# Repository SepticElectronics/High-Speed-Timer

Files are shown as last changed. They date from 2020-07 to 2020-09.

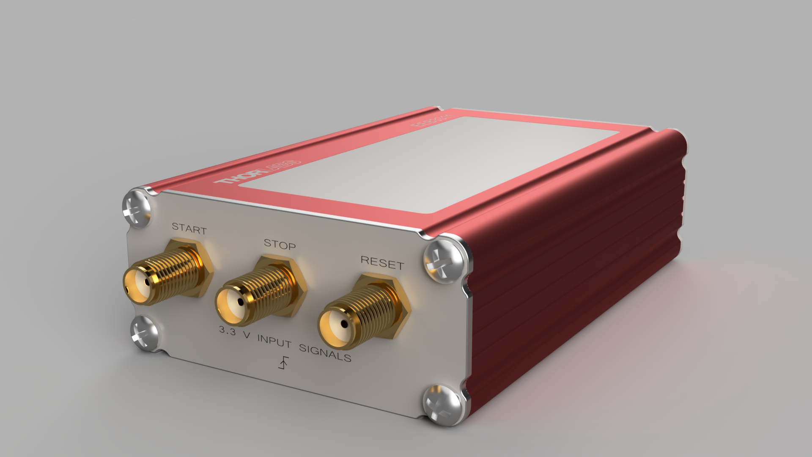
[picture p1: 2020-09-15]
PrecisionTimer_RevG.1/render/Assembly_2020-Sep-15_06-22-50PM-000_CustomizedView11693946408.png

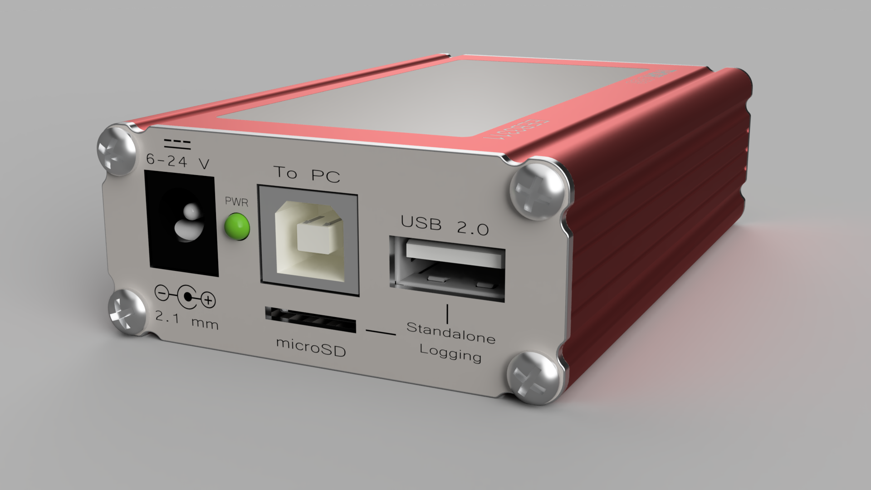
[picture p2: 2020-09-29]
PrecisionTimer_RevG.1/render/Assembly_2020-Sep-15_10-48-06PM-000_CustomizedView6473372374.png

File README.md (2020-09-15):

# High Speed Precision Timer SEHSPT554

A simple digital timer based on the TDC7200 for high-precision, short burst time measurement with a resolution of up to 55 ps. 
Long interval, low precision time measurement is done using a 125 MHz oscillator and a DDR-type clocked synchronous counter, implemented in a MachXO2 FPGA with a theoretical resolution of 4 ns.
The data collection and interfacing is handled by an ATSAM4S Microcontroller.
Two USB 2.0 and a MicroSD Interface are available for data collection.

If connected to a PC via USB-B the device is fully USB-Bus-powered.
In the case of only using a microSD-Card or a USB thumb drive, the device must be powered from a 6-24 V Barrel Connector (5.5 x 2.1 mm or 5.5 x 2.5 mm, Center Positive).

A MIPI10 JTAG programming header is available and can be used for reprogramming the FPGA or for a boundary scan of both the FPGA and the MCU. 
A 4-Pin (2.54 mm) UART connector is provided for reprogramming the MCU.
Three SMA connectors are used with 3.3 V LVCMOS signal-level for triggering and resetting the measurements.

The PCB is designed to fit inside the Thorlabs EEB3311 housing.

*This project started out as a Product Design / Layout challenge for myself and is still in a very early WIP-stage. Any (constructive) input is very much appreciated.*
**Please note that all of the mentioned features are purely implemented on a PCB / Schematic level. No software, except for the FPGA configuration, has been written yet.**

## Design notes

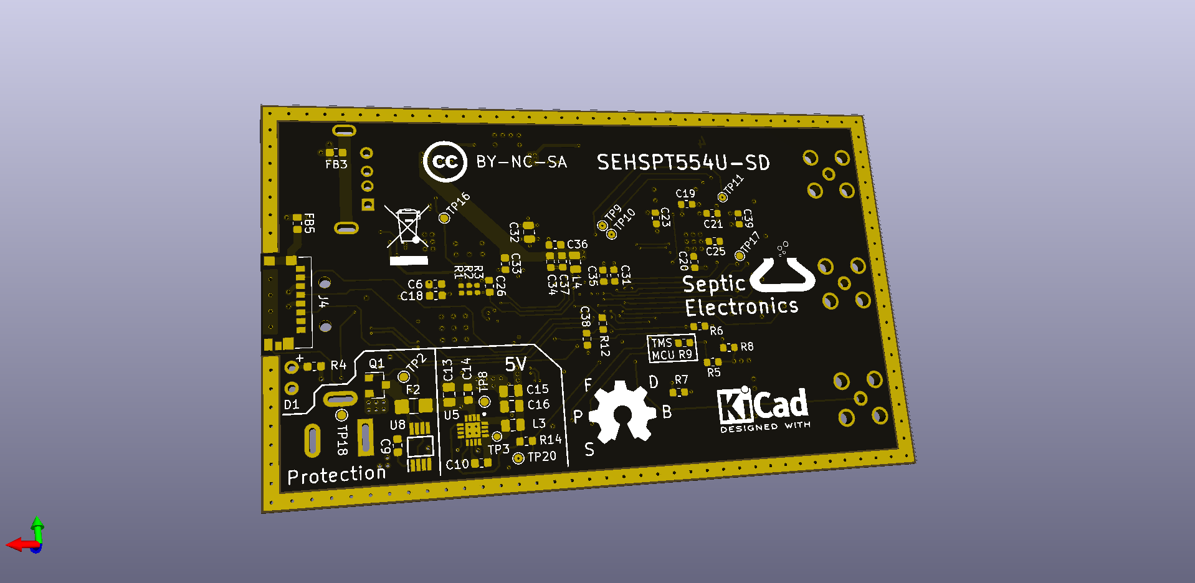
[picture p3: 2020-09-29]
PrecisionTimer_RevG.1/render/PrecisionTimer_RevG-1_Back1.png

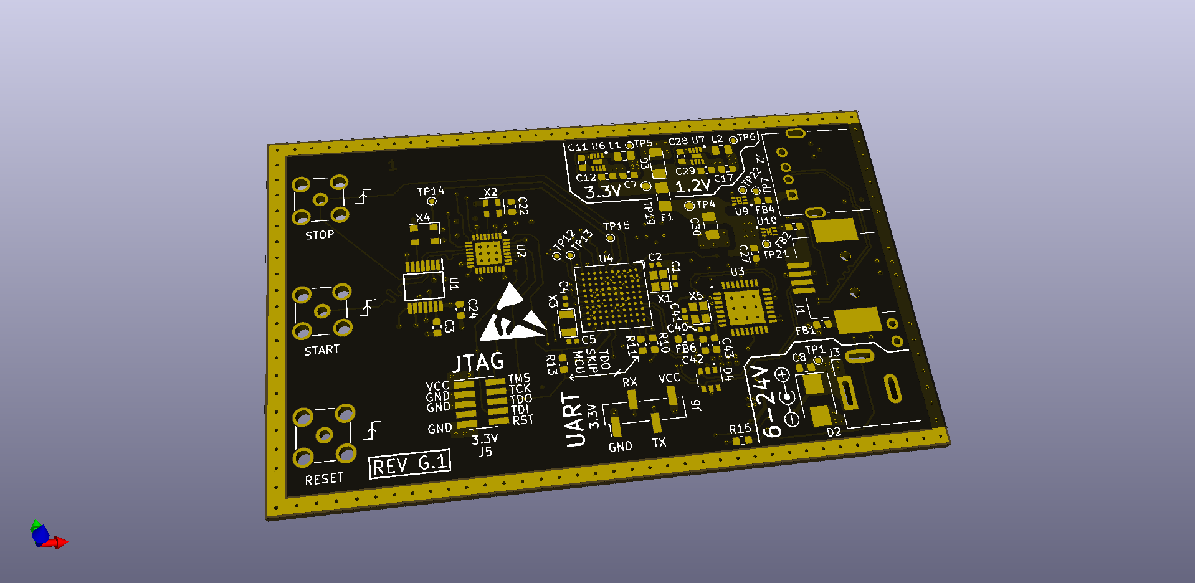
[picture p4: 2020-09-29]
PrecisionTimer_RevG.1/render/PrecisionTimer_RevG-1_Front1.png

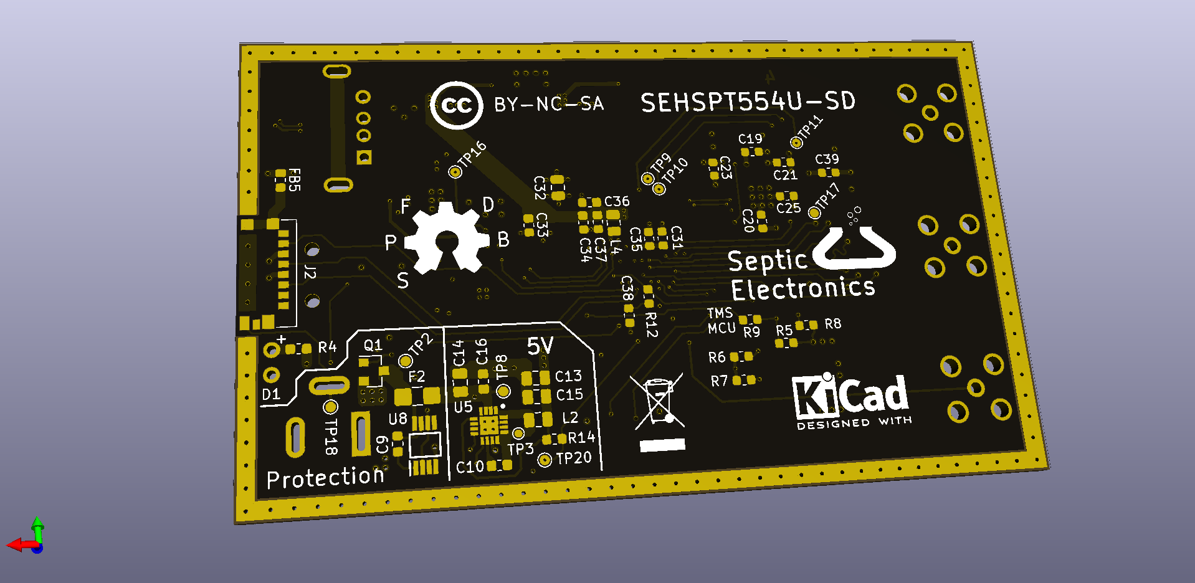
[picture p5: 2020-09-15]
PrecisionTimer_RevG/render/PrecisionTimer_RevG_B1.png

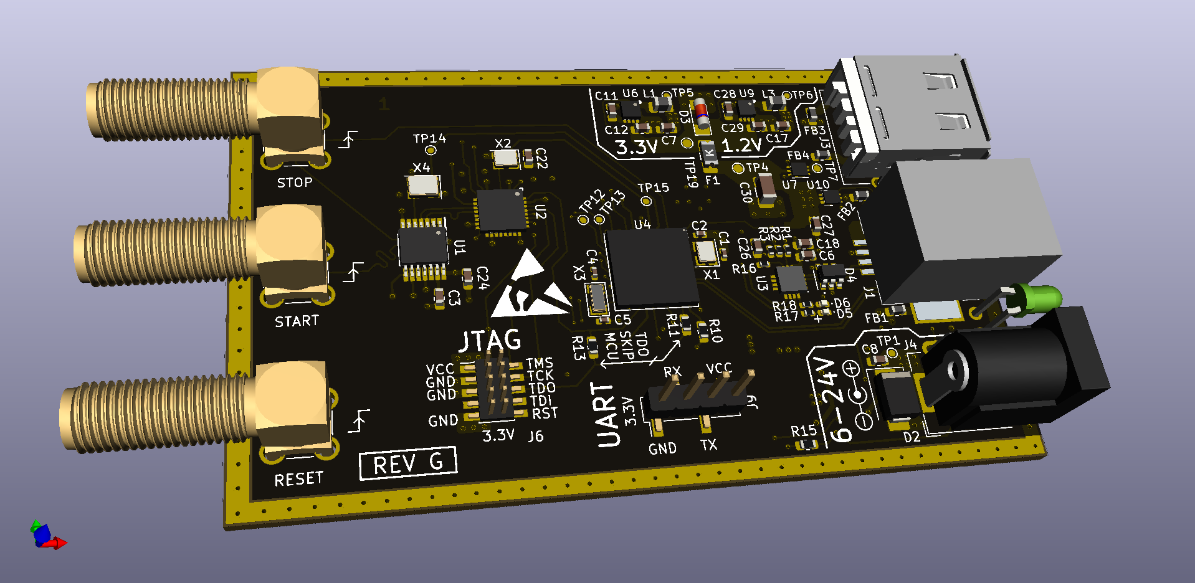
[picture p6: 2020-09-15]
PrecisionTimer_RevG/render/PrecisionTimer_RevG_F2.png

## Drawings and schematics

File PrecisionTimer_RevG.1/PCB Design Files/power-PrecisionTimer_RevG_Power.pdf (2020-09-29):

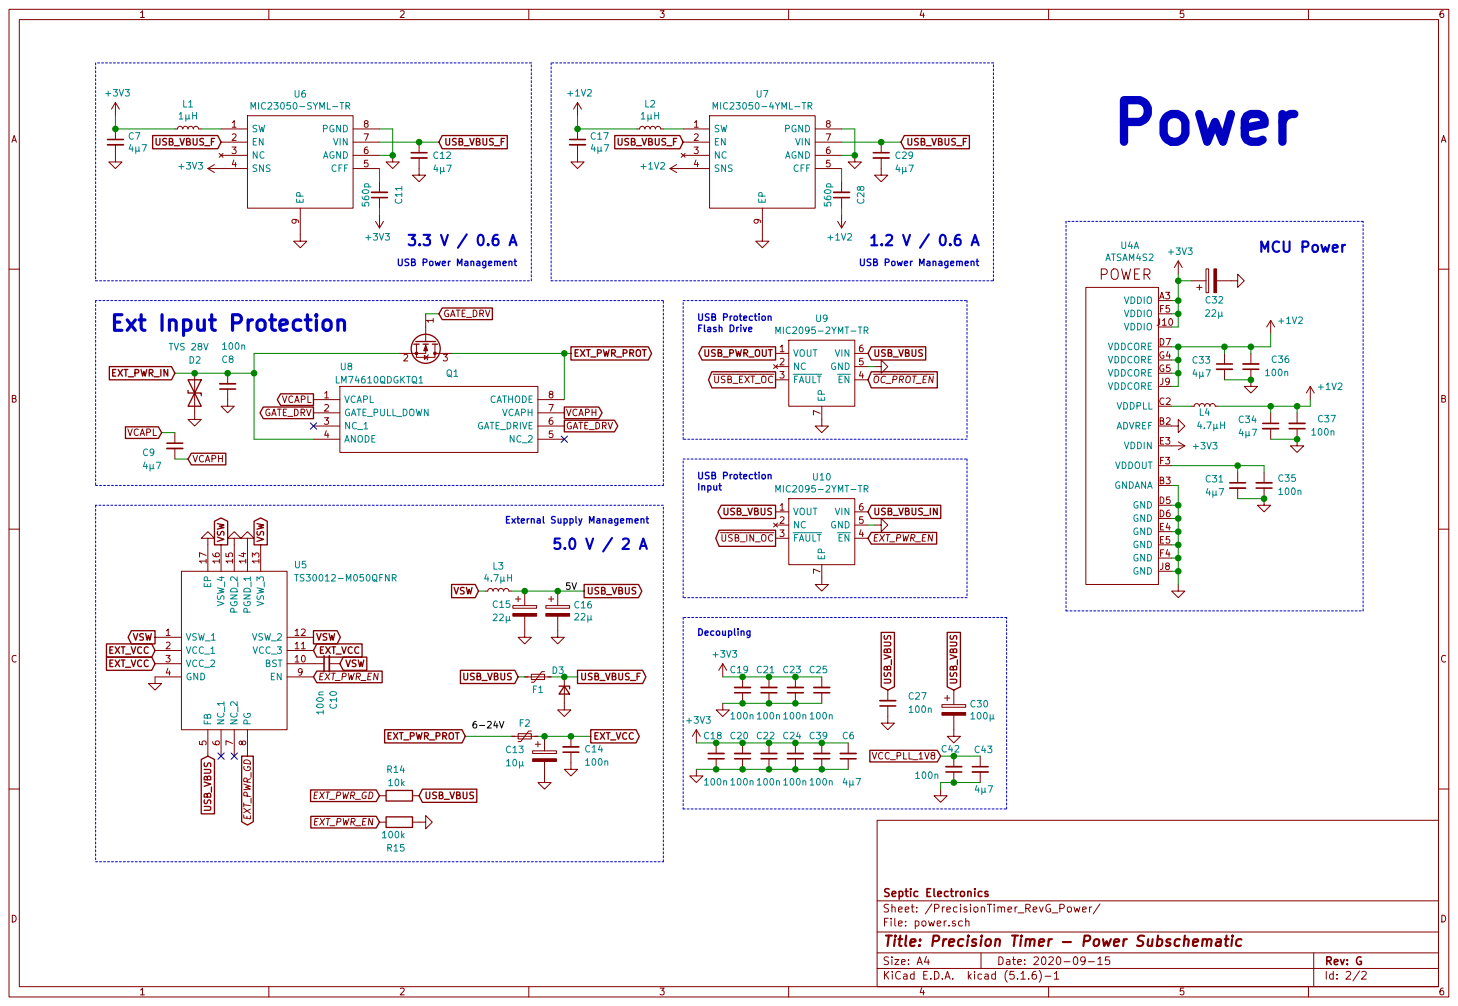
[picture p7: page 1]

7 U10 MIC2095-2YMT-TR C10 100n VOUT 1 NC 2 FAULT 3 EN 4 GND 5 VIN 6 EP

Sheet: /PrecisionTimer_RevG_Power/
File: power.sch
Id: 2/2 Title: Precision Timer - Power Subschematic

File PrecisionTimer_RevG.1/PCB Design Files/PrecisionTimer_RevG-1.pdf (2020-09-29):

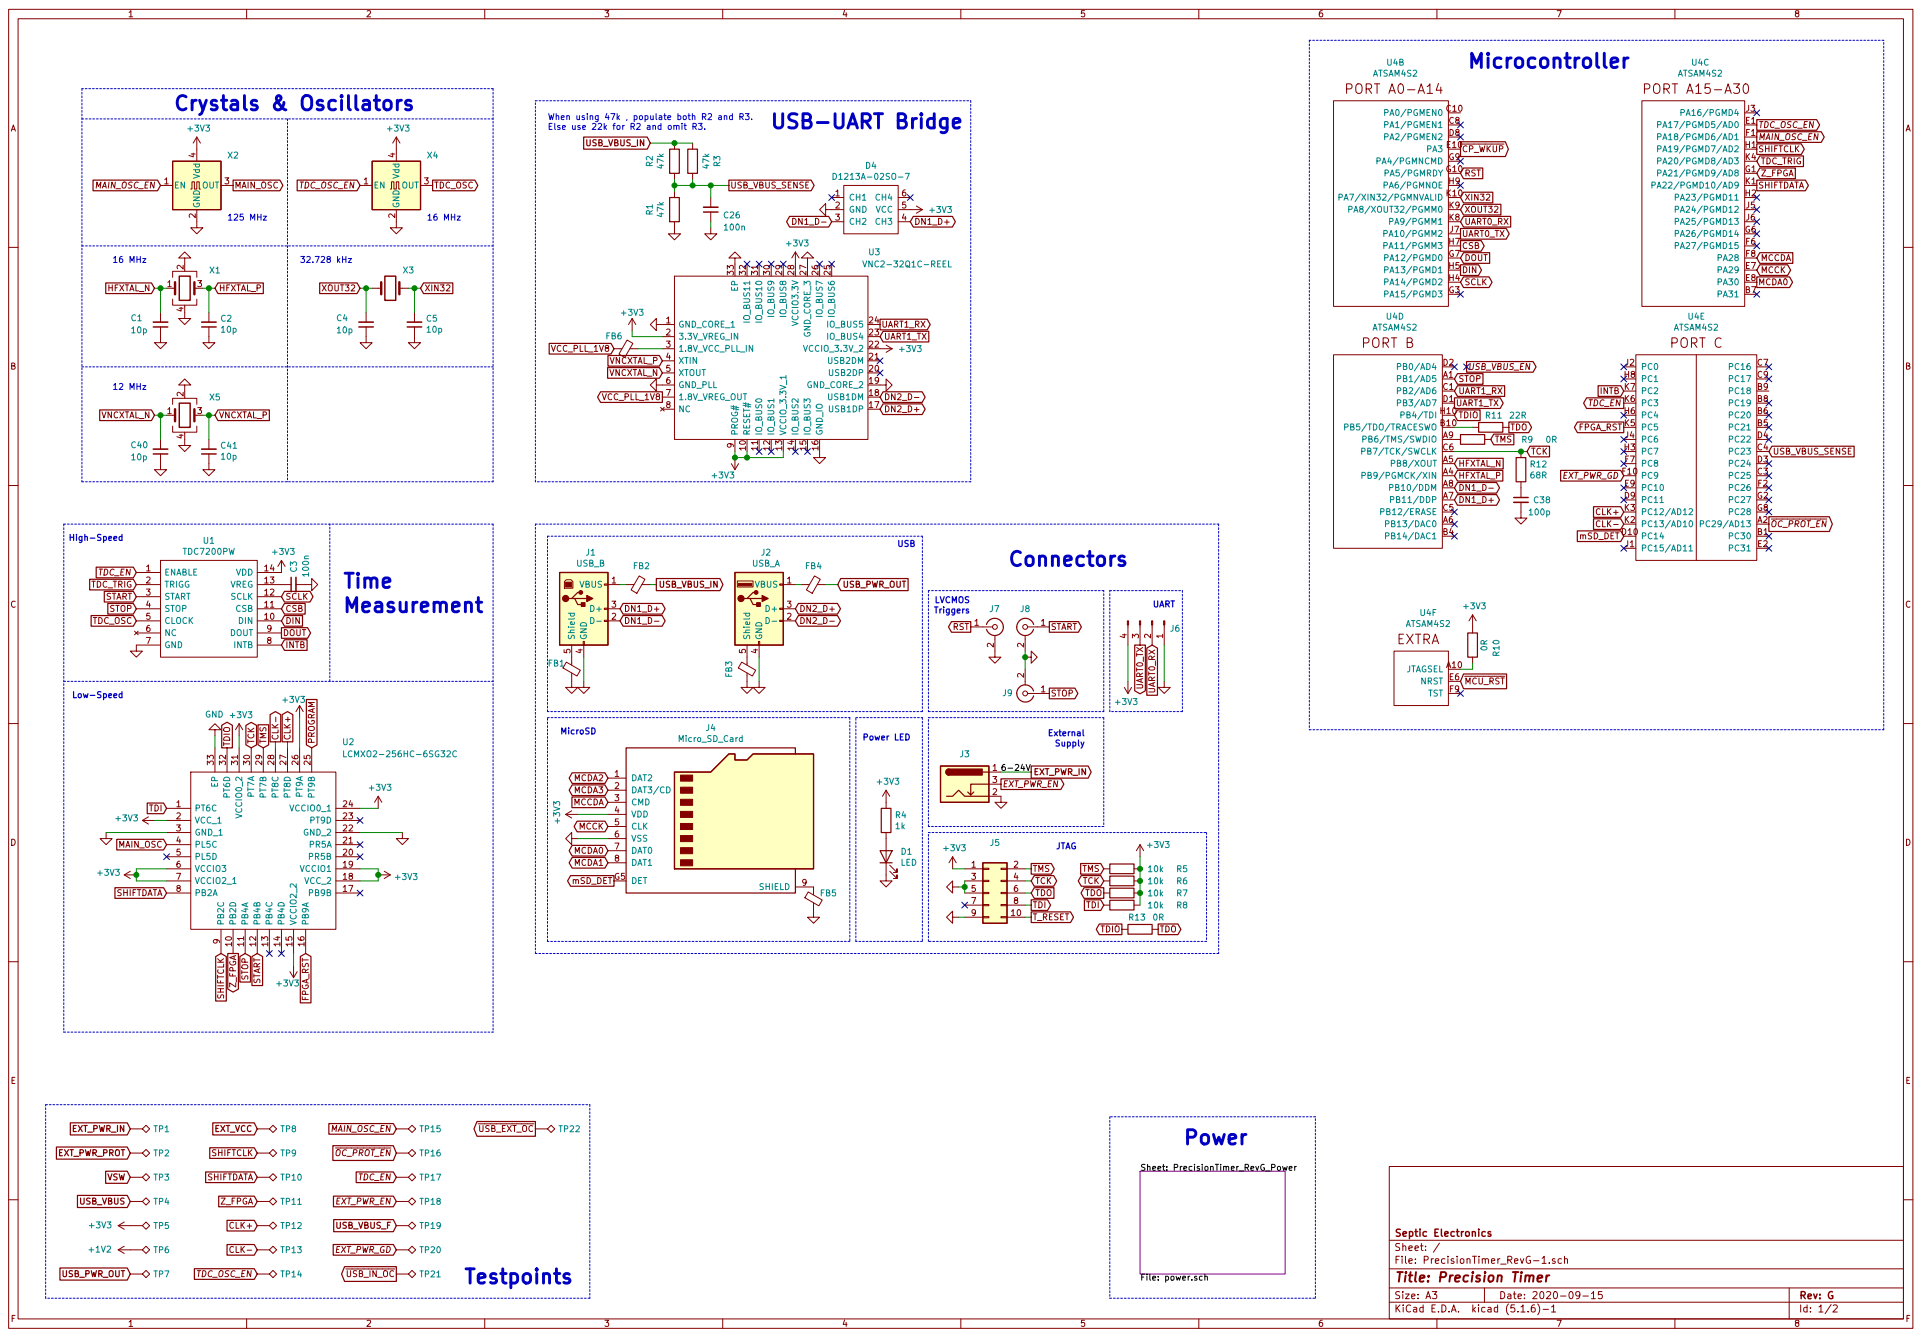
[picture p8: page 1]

External Supply Crystals & Oscillators

UART When using 47k , populate both R2 and R3. Else use 22k for R2 and omit R3.

Time Measurement

Low-Speed

Id: 1/2 Title: Precision Timer File: PrecisionTimer_RevG-1.sch Sheet: / Septic Electronics Sheet: PrecisionTimer_RevG_Power File: power.sch

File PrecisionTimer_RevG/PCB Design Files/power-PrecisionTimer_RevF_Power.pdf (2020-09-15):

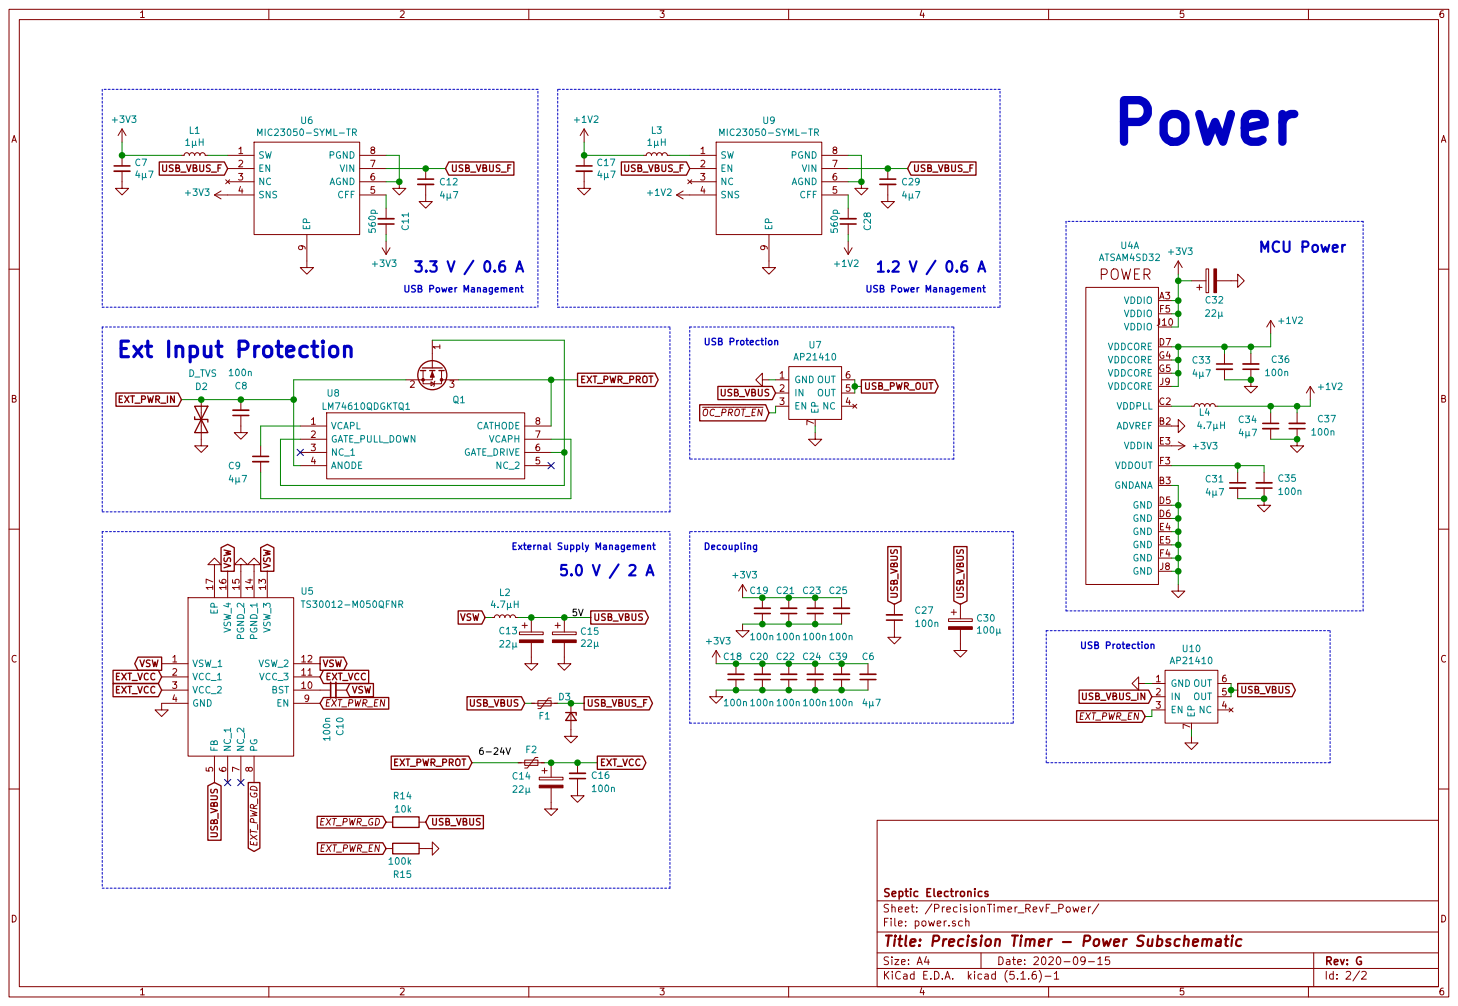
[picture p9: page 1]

MCU Power

Septic Electronics
Sheet: /PrecisionTimer_RevF_Power/
File: power.sch
Id: 2/2 Title: Precision Timer - Power Subschematic

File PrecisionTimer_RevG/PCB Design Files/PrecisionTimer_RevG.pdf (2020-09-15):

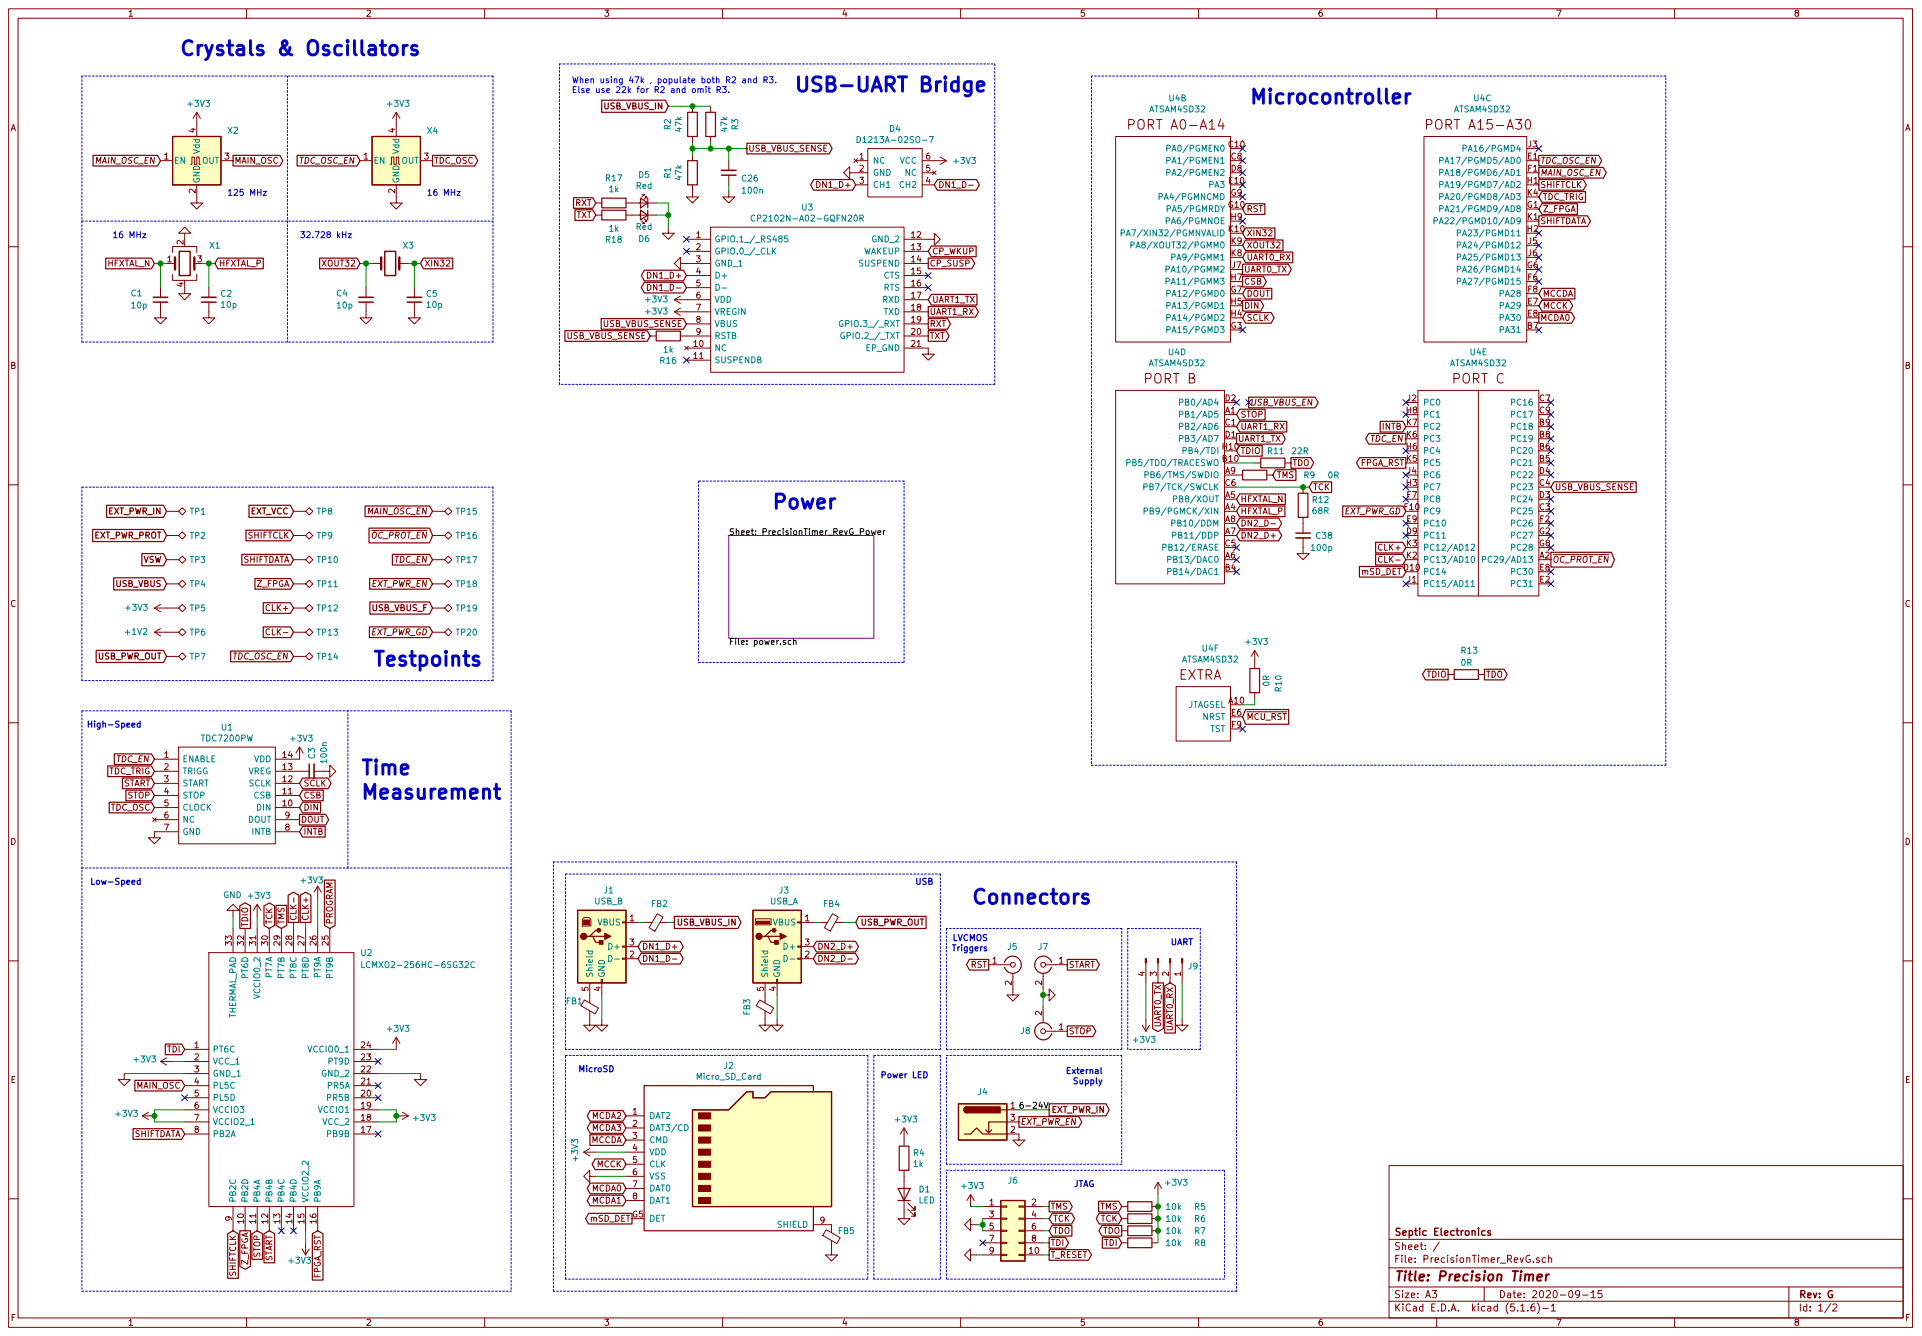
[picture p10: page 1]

When using 47k , populate both R2 and R3. Else use 22k for R2 and omit R3.

SCLK DOUT CSB DIN CLK+ EXT_PWR_PROT

Sheet: PrecisionTimer_RevG_Power File: power.sch C4

High-Speed | Time Measurement

Low-Speed

START STOP STOP START TCK MAIN_OSC

File: PrecisionTimer_RevG.sch Sheet: / Septic Electronics

Id: 1/2 Title: Precision Timer

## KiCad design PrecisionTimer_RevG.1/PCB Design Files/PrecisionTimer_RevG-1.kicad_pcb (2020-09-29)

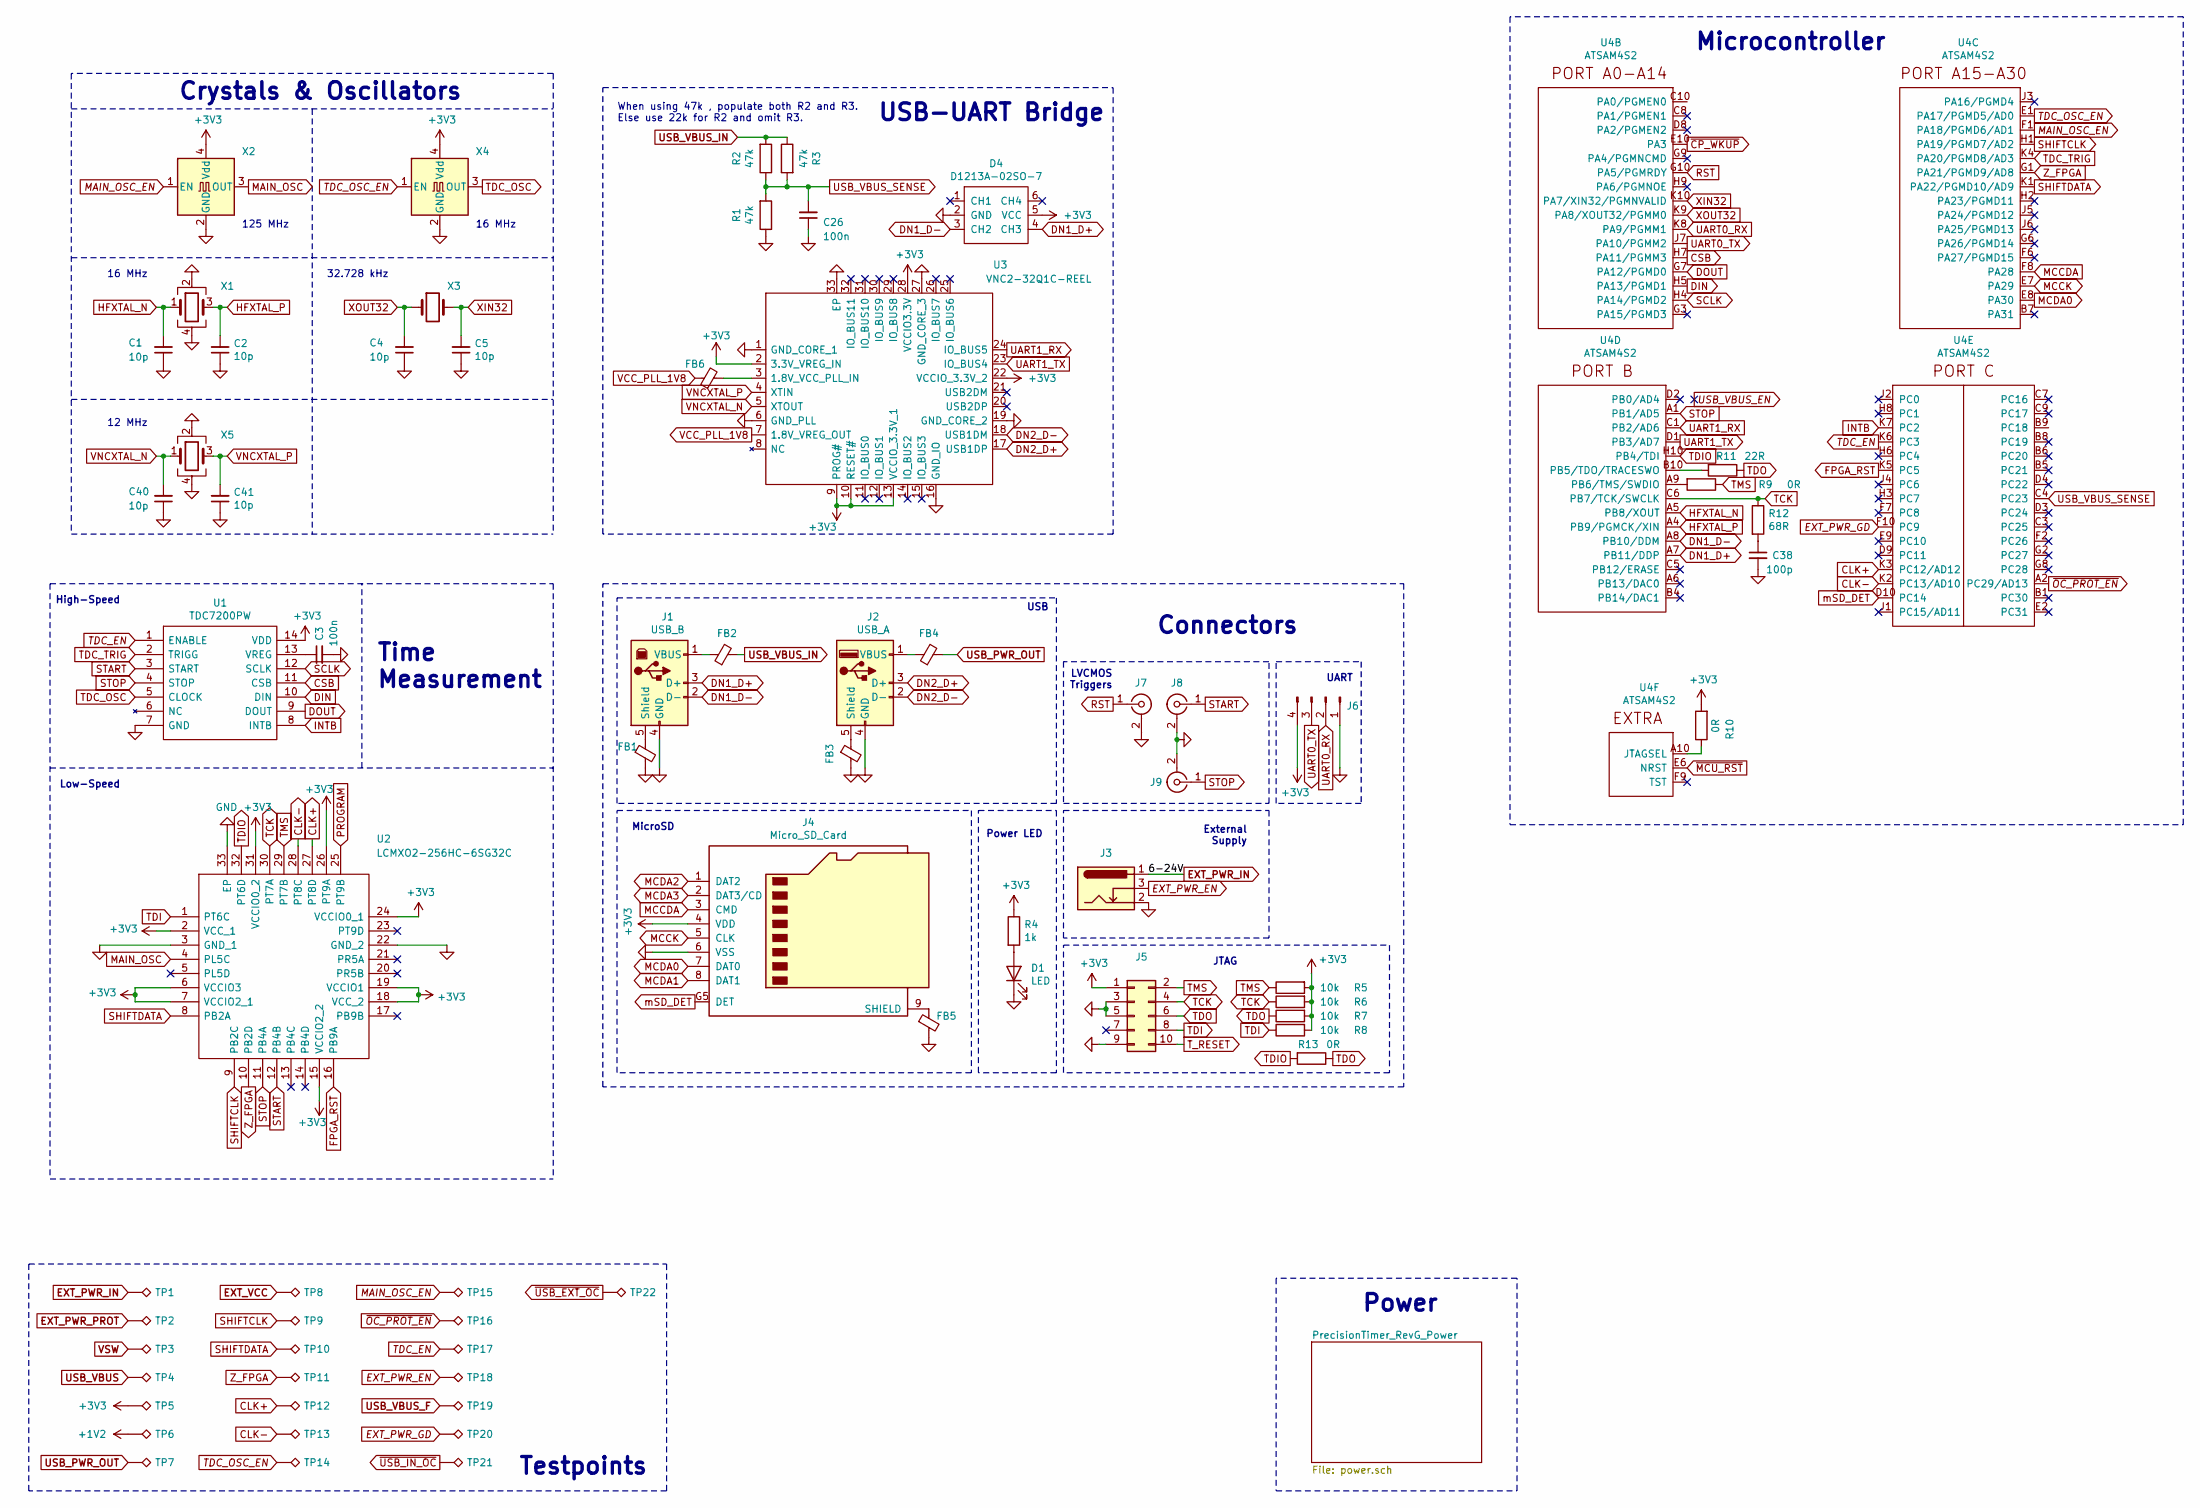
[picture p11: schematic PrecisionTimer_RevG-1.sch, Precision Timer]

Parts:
C1, C2, C4, C5, C40, C41: 10p; C_0402_1005Metric
C3, C26: 100n; C_0603_1608Metric
C38: 100p; C_0603_1608Metric
D1: LED; LED_D3.0mm
D4: D1213A-02SO-7; SOT-26
FB1, FB2, FB3, FB4, FB5, FB6: Ferrite 2A 330R; L_0603_1608Metric
J1: USB_B; KUSBEXSMTBS1NBTR
J2: USB_A; USB_A_Molex_67643_Horizontal
J3: Barrel_Jack_Switch; BarrelJack_Wuerth_6941xx301002
J4: Micro_SD_Card; 475710001
J5: Conn_02x05_Odd_Even; PinHeader_2x05_P1.27mm_Vertical_SMD
J6: Conn_01x04_Male; PinHeader_1x04_P2.54mm_Vertical_SMD_Pin1Left
J7, J8, J9: Conn_Coaxial; SMA_Molex_73251-2200_Horizontal
R1, R2, R3: 47k; R_0402_1005Metric
R4: 1k; R_0603_1608Metric
R5, R6, R7, R8: 10k; R_0603_1608Metric
R9, R10, R13: 0R; R_0603_1608Metric
R11: 22R; R_0603_1608Metric
R12: 68R; R_0603_1608Metric
TP1, TP3, TP5, TP6, TP12, TP13, TP14, TP15, TP21, TP22: TestPoint_Alt; TestPoint_Pad_D0.7mm
TP2, TP4, TP7, TP8, TP9, TP10, TP11, TP16, TP17, TP18, TP19, TP20: TestPoint_Alt; TestPoint_Pad_D1.0mm
U1: TDC7200PW; SOP65P640X120-14N; Manufacturer_Part_Number TDC7200PW
U2: LCMXO2-256HC-6SG32C; QFN50P500X500X60-33N; Manufacturer_Part_Number LCMXO2-256HC-4SG32I
U3: VNC2-32Q1C-REEL; QFN65P700X700X90-33N-D; Manufacturer_Part_Number VNC2-32Q1C-REEL; Mouser Part Number 895-VNC2-32Q1C-REEL
U4: ATSAM4S2; TFBGA-100_9.0x9.0mm_Layout10x10_P0.8mm
X1, X5: ECS-160-8-36B-CKY-TR; Crystal_SMD_2520-4Pin_2.5x2.0mm
X2: DSC1001DI2-125.0000; Oscillator_SMD_SeikoEpson_SG210-4Pin_2.5x2.0mm
X3: FC-135 32.7680KA-AG0; Crystal_SMD_3215-2Pin_3.2x1.5mm
X4: ECS-3225S33-160-FN-TR; Oscillator_SMD_EuroQuartz_XO32-4Pin_3.2x2.5mm

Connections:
+1V2: TP6.1; also elsewhere on the board
+3V3: D4.5 (VCC), J4.4 (VDD), J5.1, J6.4, R4.1, R5.2, R6.2, R7.2, R8.2, R10.2, TP5.1, U1.14 (VDD), U2.2 (VCC_1), U2.6 (VCCIO3), U2.7 (VCCIO2_1), U2.15 (VCCIO2_2), U2.18 (VCC_2), U2.19 (VCCIO1), U2.24 (VCCIO0_1), U2.26 (PT9A), U2.31 (VCCIO0_2), U3.2 (3.3V_VREG_IN), U3.9 (PROG#), U3.10 (RESET#), U3.13 (VCCIO_3.3V_1), U3.22 (VCCIO_3.3V_2), U3.28 (VCCIO3.3V), X2.4 (Vdd), X4.4 (Vdd); also elsewhere on the board
CLK+: TP12.1, U2.27 (PT8D), U4.K3 (PC12/AD12)
CLK-: TP13.1, U2.28 (PT8C), U4.K2 (PC13/AD10)
CSB: U1.11 (CSB), U4.H7 (PA11/PGMM3)
DIN: U1.10 (DIN), U4.H5 (PA13/PGMD1)
DN1_D+: D4.4 (CH3), J1.3 (D+), U4.A7 (PB11/DDP)
DN1_D-: D4.3 (CH2), J1.2 (D-), U4.A8 (PB10/DDM)
DN2_D+: J2.3 (D+), U3.17 (USB1DP)
DN2_D-: J2.2 (D-), U3.18 (USB1DM)
DOUT: U1.9 (DOUT), U4.G7 (PA12/PGMD0)
EXT_PWR_EN: J3.3, TP18.1; also elsewhere on the board
EXT_PWR_GD: TP20.1, U4.F10 (PC9); also elsewhere on the board
EXT_PWR_IN: J3.1, TP1.1; also elsewhere on the board
EXT_PWR_PROT: TP2.1; also elsewhere on the board
EXT_VCC: TP8.1; also elsewhere on the board
FPGA_RST: U2.16 (PB9A), U4.K5 (PC5)
GND: C1.1, C2.1, C3.2, C4.1, C5.1, C26.1, C38.2, C40.1, C41.1, D1.1 (K), D4.2 (GND), FB1.2, FB3.2, FB5.2, J1.4 (GND), J2.4 (GND), J3.2, J4.6 (VSS), J5.3, J5.5, J5.9, J6.1, J7.2 (Ext), J8.2 (Ext), J9.2 (Ext), R1.1, U1.7 (GND), U2.3 (GND_1), U2.22 (GND_2), U2.33 (EP), U3.1 (GND_CORE_1), U3.6 (GND_PLL), U3.16 (GND_IO), U3.19 (GND_CORE_2), U3.27 (GND_CORE_3), U3.33 (EP), X1.2, X1.4, X2.2 (GND), X4.2 (GND), X5.2, X5.4; also elsewhere on the board
HFXTAL_N: C1.2, U4.A5 (PB8/XOUT), X1.1
HFXTAL_P: C2.2, U4.A4 (PB9/PGMCK/XIN), X1.3
INTB: U1.8 (INTB), U4.K7 (PC2)
MAIN_OSC: U2.4 (PL5C), X2.3 (OUT)
MAIN_OSC_EN: TP15.1, U4.F1 (PA18/PGMD6/AD1), X2.1 (EN)
MCCDA: J4.3 (CMD), U4.F8 (PA28)
MCCK: J4.5 (CLK), U4.E7 (PA29)
MCDA0: J4.7 (DAT0), U4.E8 (PA30)
MCDA1: J4.8 (DAT1)
MCDA2: J4.1 (DAT2)
MCDA3: J4.2 (DAT3/CD)
unnamed: C3.1, U1.13 (VREG)
unnamed: C38.1, R12.2
unnamed: D1.2 (A), R4.2
unnamed: FB1.1, J1.5 (Shield)
unnamed: FB2.1, J1.1 (VBUS)
unnamed: FB3.1, J2.5 (Shield)
unnamed: FB4.1, J2.1 (VBUS)
unnamed: FB5.1, J4.9 (SHIELD)
unnamed: FB6.2, U3.3 (1.8V_VCC_PLL_IN)
unnamed: R9.2, U4.A9 (PB6/TMS/SWDIO)
unnamed: R10.1, U4.A10 (JTAGSEL)
unnamed: R11.2, U4.B10 (PB5/TDO/TRACESWO)
PROGRAM: U2.25 (PT9B)
RST: J7.1 (In), U4.G10 (PA5/PGMRDY)
SCLK: U1.12 (SCLK), U4.H4 (PA14/PGMD2)
SHIFTCLK: TP9.1, U2.9 (PB2C), U4.H1 (PA19/PGMD7/AD2)
SHIFTDATA: TP10.1, U2.8 (PB2A), U4.K1 (PA22/PGMD10/AD9)
START: J8.1 (In), U1.3 (START), U2.12 (PB4B)
STOP: J9.1 (In), U1.4 (STOP), U2.11 (PB4A), U4.A1 (PB1/AD5)
TCK: J5.4, R6.1, R12.1, U2.30 (PT7A), U4.C6 (PB7/TCK/SWCLK)
TDC_EN: TP17.1, U1.1 (ENABLE), U4.K6 (PC3)
TDC_OSC: U1.5 (CLOCK), X4.3 (OUT)
TDC_OSC_EN: TP14.1, U4.E1 (PA17/PGMD5/AD0), X4.1 (EN)
TDC_TRIG: U1.2 (TRIGG), U4.K4 (PA20/PGMD8/AD3)
TDI: J5.8, R8.1, U2.1 (PT6C)
TDIO: R13.2, U2.32 (PT6D), U4.H10 (PB4/TDI)
TDO: J5.6, R7.1, R11.1, R13.1
TMS: J5.2, R5.1, R9.1, U2.29 (PT7B)
T_RESET: J5.10
UART0_RX: J6.2, U4.K8 (PA9/PGMM1)
UART0_TX: J6.3, U4.J7 (PA10/PGMM2)
UART1_RX: U3.24 (IO_BUS5), U4.C1 (PB2/AD6)
UART1_TX: U3.23 (IO_BUS4), U4.D1 (PB3/AD7)
USB_PWR_OUT: FB4.2, TP7.1; also elsewhere on the board
USB_VBUS: TP4.1; also elsewhere on the board
USB_VBUS_F: TP19.1; also elsewhere on the board
USB_VBUS_IN: FB2.2, R2.2, R3.1; also elsewhere on the board
USB_VBUS_SENSE: C26.2, R1.2, R2.1, R3.2, U4.C4 (PC23)
VCC_PLL_1V8: FB6.1, U3.7 (1.8V_VREG_OUT); also elsewhere on the board
VNCXTAL_N: C40.2, U3.5 (XTOUT), X5.1
VNCXTAL_P: C41.2, U3.4 (XTIN), X5.3
VSW: TP3.1; also elsewhere on the board
XIN32: C5.2, U4.K10 (PA7/XIN32/PGMNVALID), X3.2
XOUT32: C4.2, U4.K9 (PA8/XOUT32/PGMM0), X3.1
Z_FPGA: TP11.1, U2.10 (PB2D), U4.G1 (PA21/PGMD9/AD8)
mSD_DET: J4.G5 (DET), U4.D10 (PC14)
~CP_WKUP: U4.E10 (PA3)
~MCU_RST: U4.E6 (NRST)
~OC_PROT_EN: TP16.1, U4.A2 (PC29/AD13); also elsewhere on the board
~USB_EXT_OC: TP22.1; also elsewhere on the board
~USB_IN_OC: TP21.1; also elsewhere on the board

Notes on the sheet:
Time Measurement
Connectors
Power LED
Microcontroller
LVCMOS Triggers
Low-Speed
USB
JTAG
External Supply
UART
MicroSD
USB-UART Bridge
High-Speed
Testpoints
125 MHz
16 MHz
Power
32.728 kHz
When using 47k , populate both R2 and R3. Else use 22k for R2 and omit R3.
Crystals & Oscillators
12 MHz

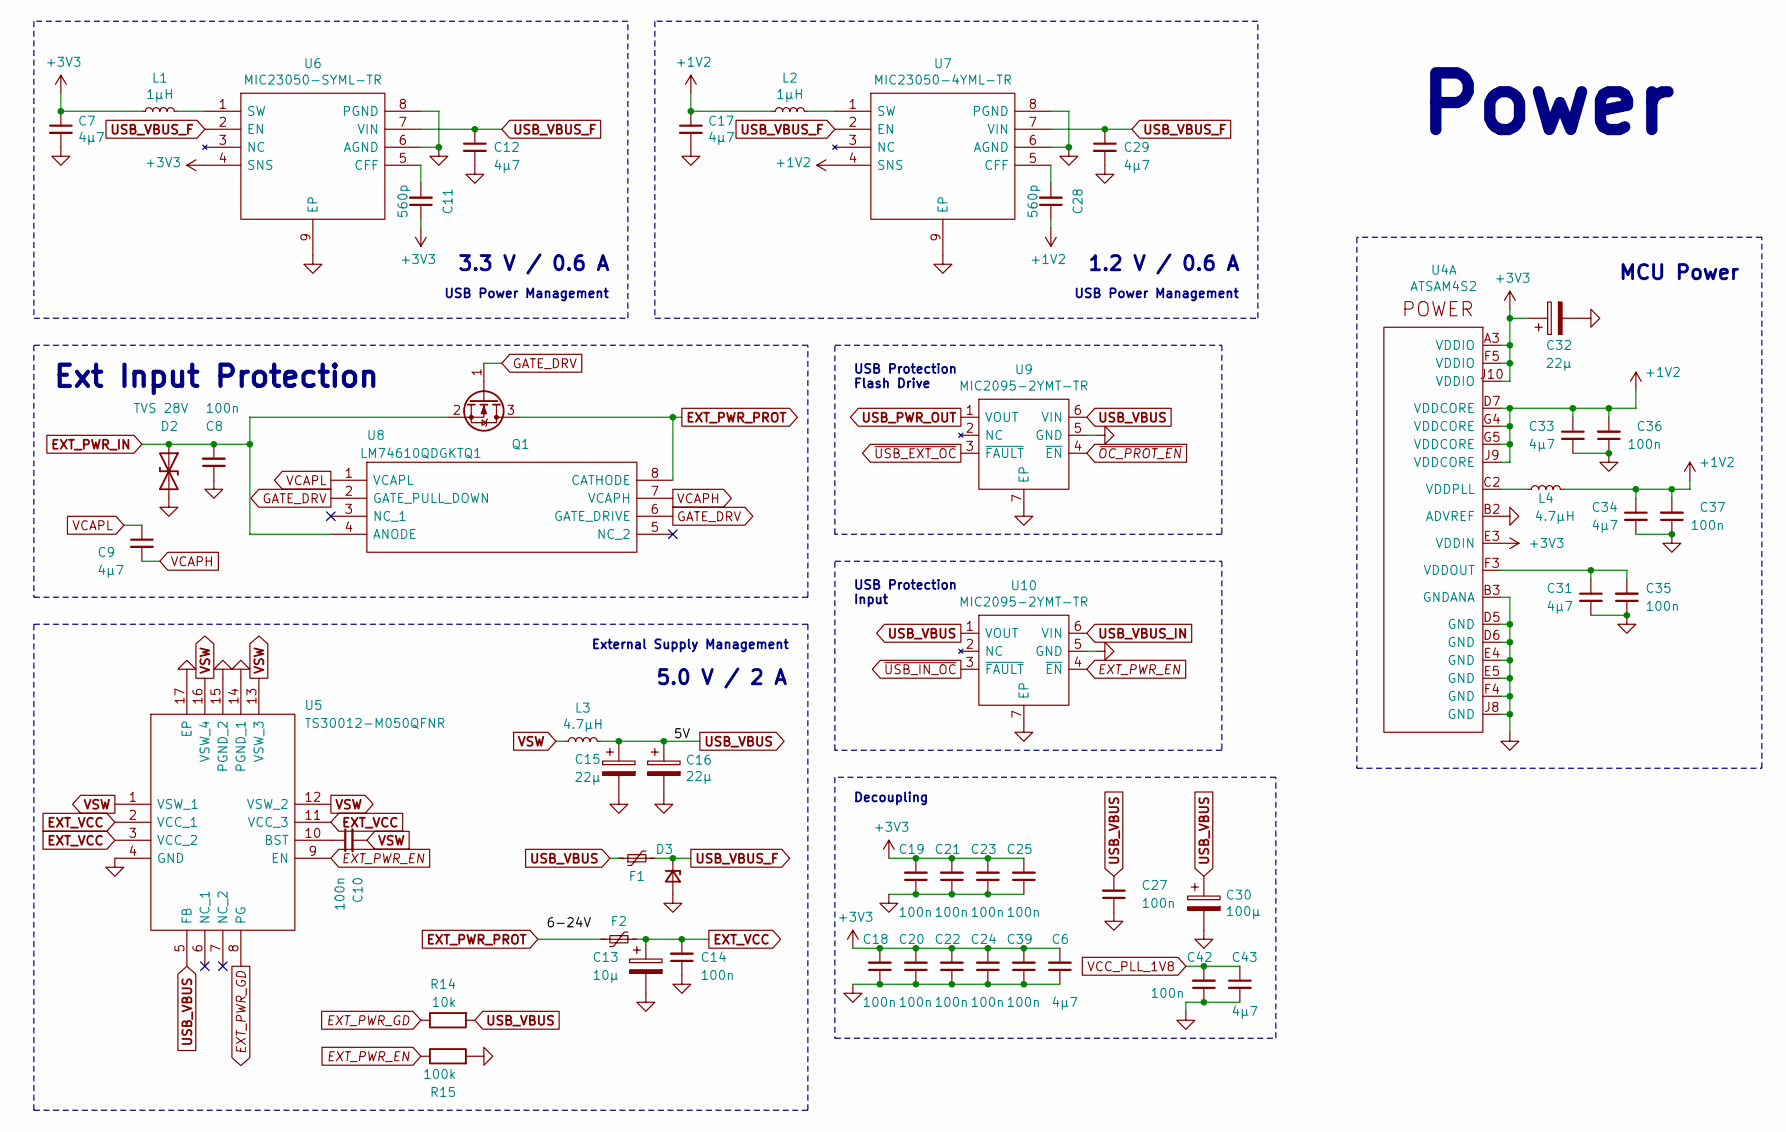
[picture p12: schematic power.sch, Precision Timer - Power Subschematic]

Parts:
C6, C7, C9, C12, C17, C29, C31, C33, C34, C43: 4µ7; C_0603_1608Metric
C8, C10, C14, C18, C19, C20, C21, C22, C23, C24, C25, C27, C35, C36, C37, C39, C42: 100n; C_0603_1608Metric
C11, C28: 560p; C_0603_1608Metric
C13: 10µ; C_0805_2012Metric
C15, C16, C32: 22µ; C_0805_2012Metric
C30: 100µ; C_1206_3216Metric
D2: TVS 28V; D_SMB; Voltage 30 V
D3: Zener 5.6V; D_MiniMELF
F1, F2: Polyfuse 500 mA; Fuse_1206_3216Metric_Castellated
L1, L2: 1µH; L_0805_2012Metric
L3, L4: 4.7µH; L_0805_2012Metric
Q1: NMOS 2A; SOT-23
R14: 10k; R_0603_1608Metric
R15: 100k; R_0603_1608Metric
U4: ATSAM4S2; TFBGA-100_9.0x9.0mm_Layout10x10_P0.8mm
U5: TS30012-M050QFNR; QFN50P300X300X100-17N-D; Manufacturer_Part_Number TS30012-M050QFNR; Mouser Part Number 947-TS30012-M050QFNR
U6: MIC23050-SYML-TR; SON50P200X200X90-9N; Manufacturer_Part_Number MIC23050-SYML-TR; Mouser Part Number 998-MIC23050-SYMLTR
U7: MIC23050-4YML-TR; SON50P200X200X90-9N; Manufacturer_Part_Number MIC23050-SYML-TR; Mouser Part Number 998-MIC23050-SYMLTR
U8: LM74610QDGKTQ1; SOP65P490X110-8N; Manufacturer_Part_Number LM74610QDGKTQ1; Mouser Part Number 595-LM74610QDGKTQ1
U9, U10: MIC2095-2YMT-TR; SON50P160X160X60-7N-D; Manufacturer_Part_Number MIC2095-1YMT-TR; Mouser Part Number 998-MIC2095-1YMTTR

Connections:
+1V2: C17.1, C28.1, C33.1, C34.1, C36.2, C37.2, L2.1, L4.2, U4.D7 (VDDCORE), U4.G4 (VDDCORE), U4.G5 (VDDCORE), U4.J9 (VDDCORE), U7.4 (SNS); also elsewhere on the board
+3V3: C6.2, C7.1, C11.1, C18.2, C19.2, C20.2, C21.2, C22.2, C23.2, C24.2, C25.2, C32.1, C39.2, L1.1, U4.A3 (VDDIO), U4.E3 (VDDIN), U4.F5 (VDDIO), U4.J10 (VDDIO), U6.4 (SNS); also elsewhere on the board
EXT_PWR_EN: R15.1, U5.9 (EN), U10.4 (~EN); also elsewhere on the board
EXT_PWR_GD: R14.1, U5.8 (PG); also elsewhere on the board
EXT_PWR_IN: C8.2, D2.1 (A1), Q1.2 (S), U8.4 (ANODE); also elsewhere on the board
EXT_PWR_PROT: F2.2, Q1.3 (D), U8.8 (CATHODE); also elsewhere on the board
EXT_VCC: C13.1, C14.2, F2.1, U5.2 (VCC_1), U5.3 (VCC_2), U5.11 (VCC_3); also elsewhere on the board
GATE_DRV: Q1.1 (G), U8.2 (GATE_PULL_DOWN), U8.6 (GATE_DRIVE)
GND: C6.1, C7.2, C8.1, C12.2, C13.2, C14.1, C15.2, C16.2, C17.2, C18.1, C19.1, C20.1, C21.1, C22.1, C23.1, C24.1, C25.1, C27.1, C29.2, C30.2, C31.2, C32.2, C33.2, C34.2, C35.1, C36.1, C37.1, C39.1, C42.1, C43.2, D2.2 (A2), D3.2 (A), R15.2, U4.B2 (ADVREF), U4.B3 (GNDANA), U4.D5 (GND), U4.D6 (GND), U4.E4 (GND), U4.E5 (GND), U4.F4 (GND), U4.J8 (GND), U5.4 (GND), U5.14 (PGND_1), U5.15 (PGND_2), U5.17 (EP), U6.6 (AGND), U6.8 (PGND), U6.9 (EP), U7.6 (AGND), U7.8 (PGND), U7.9 (EP), U9.5 (GND), U9.7 (EP), U10.5 (GND), U10.7 (EP); also elsewhere on the board
unnamed: C10.1, U5.10 (BST)
unnamed: C11.2, U6.5 (CFF)
unnamed: C28.2, U7.5 (CFF)
unnamed: C31.1, C35.2, U4.F3 (VDDOUT)
unnamed: L1.2, U6.1 (SW)
unnamed: L2.2, U7.1 (SW)
unnamed: L4.1, U4.C2 (VDDPLL)
USB_PWR_OUT: U9.1 (VOUT); also elsewhere on the board
USB_VBUS: C15.1, C16.1, C27.2, C30.1, F1.1, L3.2, R14.2, U5.5 (FB), U9.6 (VIN), U10.1 (VOUT); also elsewhere on the board
USB_VBUS_F: C12.1, C29.1, D3.1 (K), F1.2, U6.2 (EN), U6.7 (VIN), U7.2 (EN), U7.7 (VIN); also elsewhere on the board
USB_VBUS_IN: U10.6 (VIN); also elsewhere on the board
VCAPH: C9.2, U8.7 (VCAPH)
VCAPL: C9.1, U8.1 (VCAPL)
VCC_PLL_1V8: C42.2, C43.1; also elsewhere on the board
VSW: C10.2, L3.1, U5.1 (VSW_1), U5.12 (VSW_2), U5.13 (VSW_3), U5.16 (VSW_4); also elsewhere on the board
~OC_PROT_EN: U9.4 (~EN); also elsewhere on the board
~USB_EXT_OC: U9.3 (~FAULT); also elsewhere on the board
~USB_IN_OC: U10.3 (~FAULT); also elsewhere on the board

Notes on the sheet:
USB Power Management
Decoupling
External Supply Management
Power
USB Protection Flash Drive
3.3 V / 0.6 A
1.2 V / 0.6 A
5.0 V / 2 A
Ext Input Protection
MCU Power
USB Protection Input

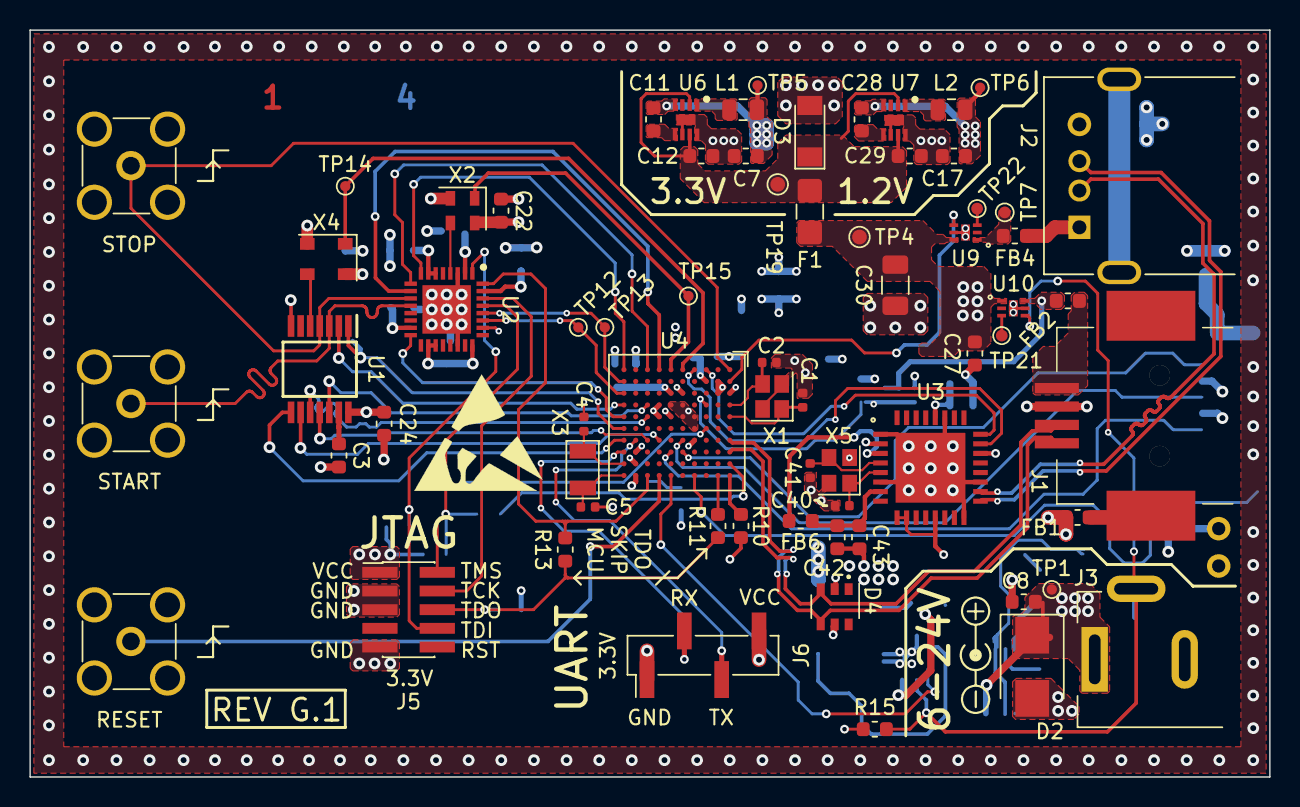
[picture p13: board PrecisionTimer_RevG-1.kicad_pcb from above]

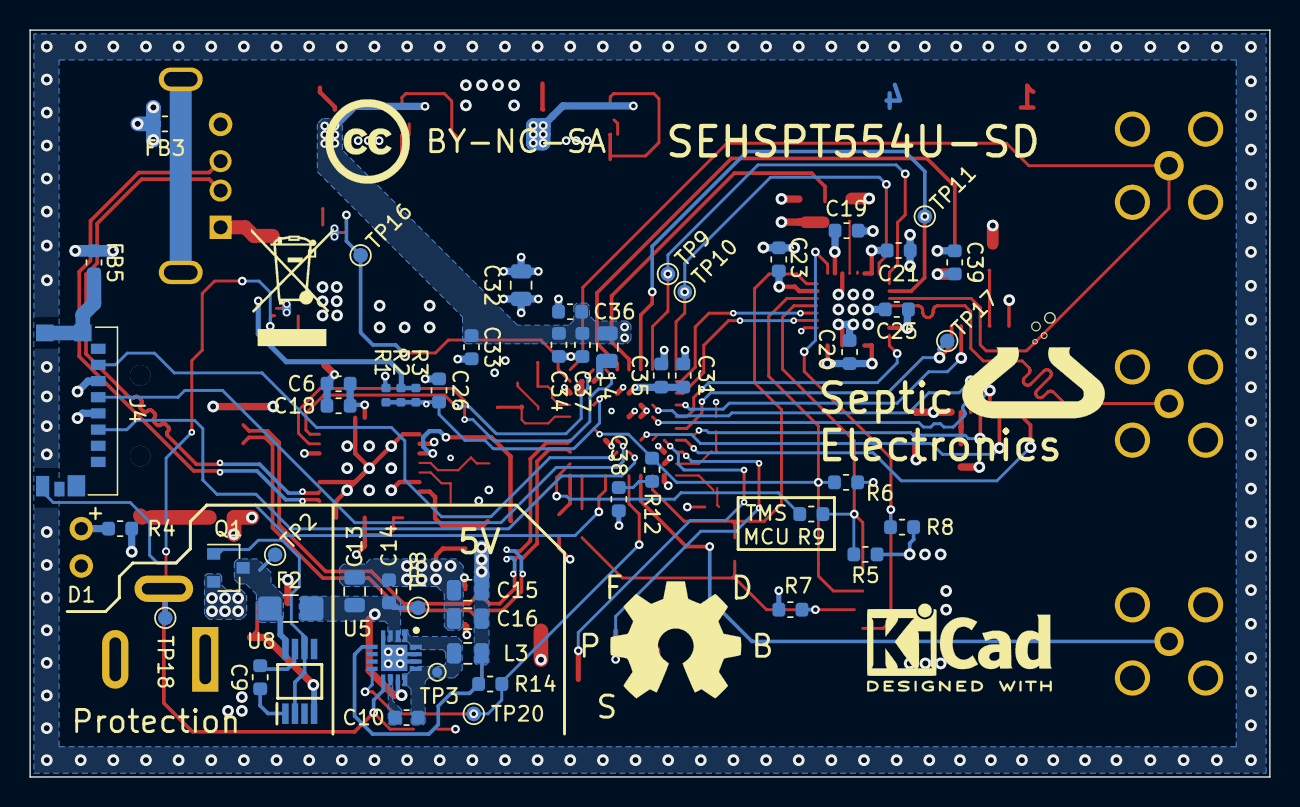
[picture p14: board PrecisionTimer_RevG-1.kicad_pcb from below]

Board: 4 copper layers, 84.3 x 50.8 mm, 121 parts (53 on the bottom side), 83 nets.

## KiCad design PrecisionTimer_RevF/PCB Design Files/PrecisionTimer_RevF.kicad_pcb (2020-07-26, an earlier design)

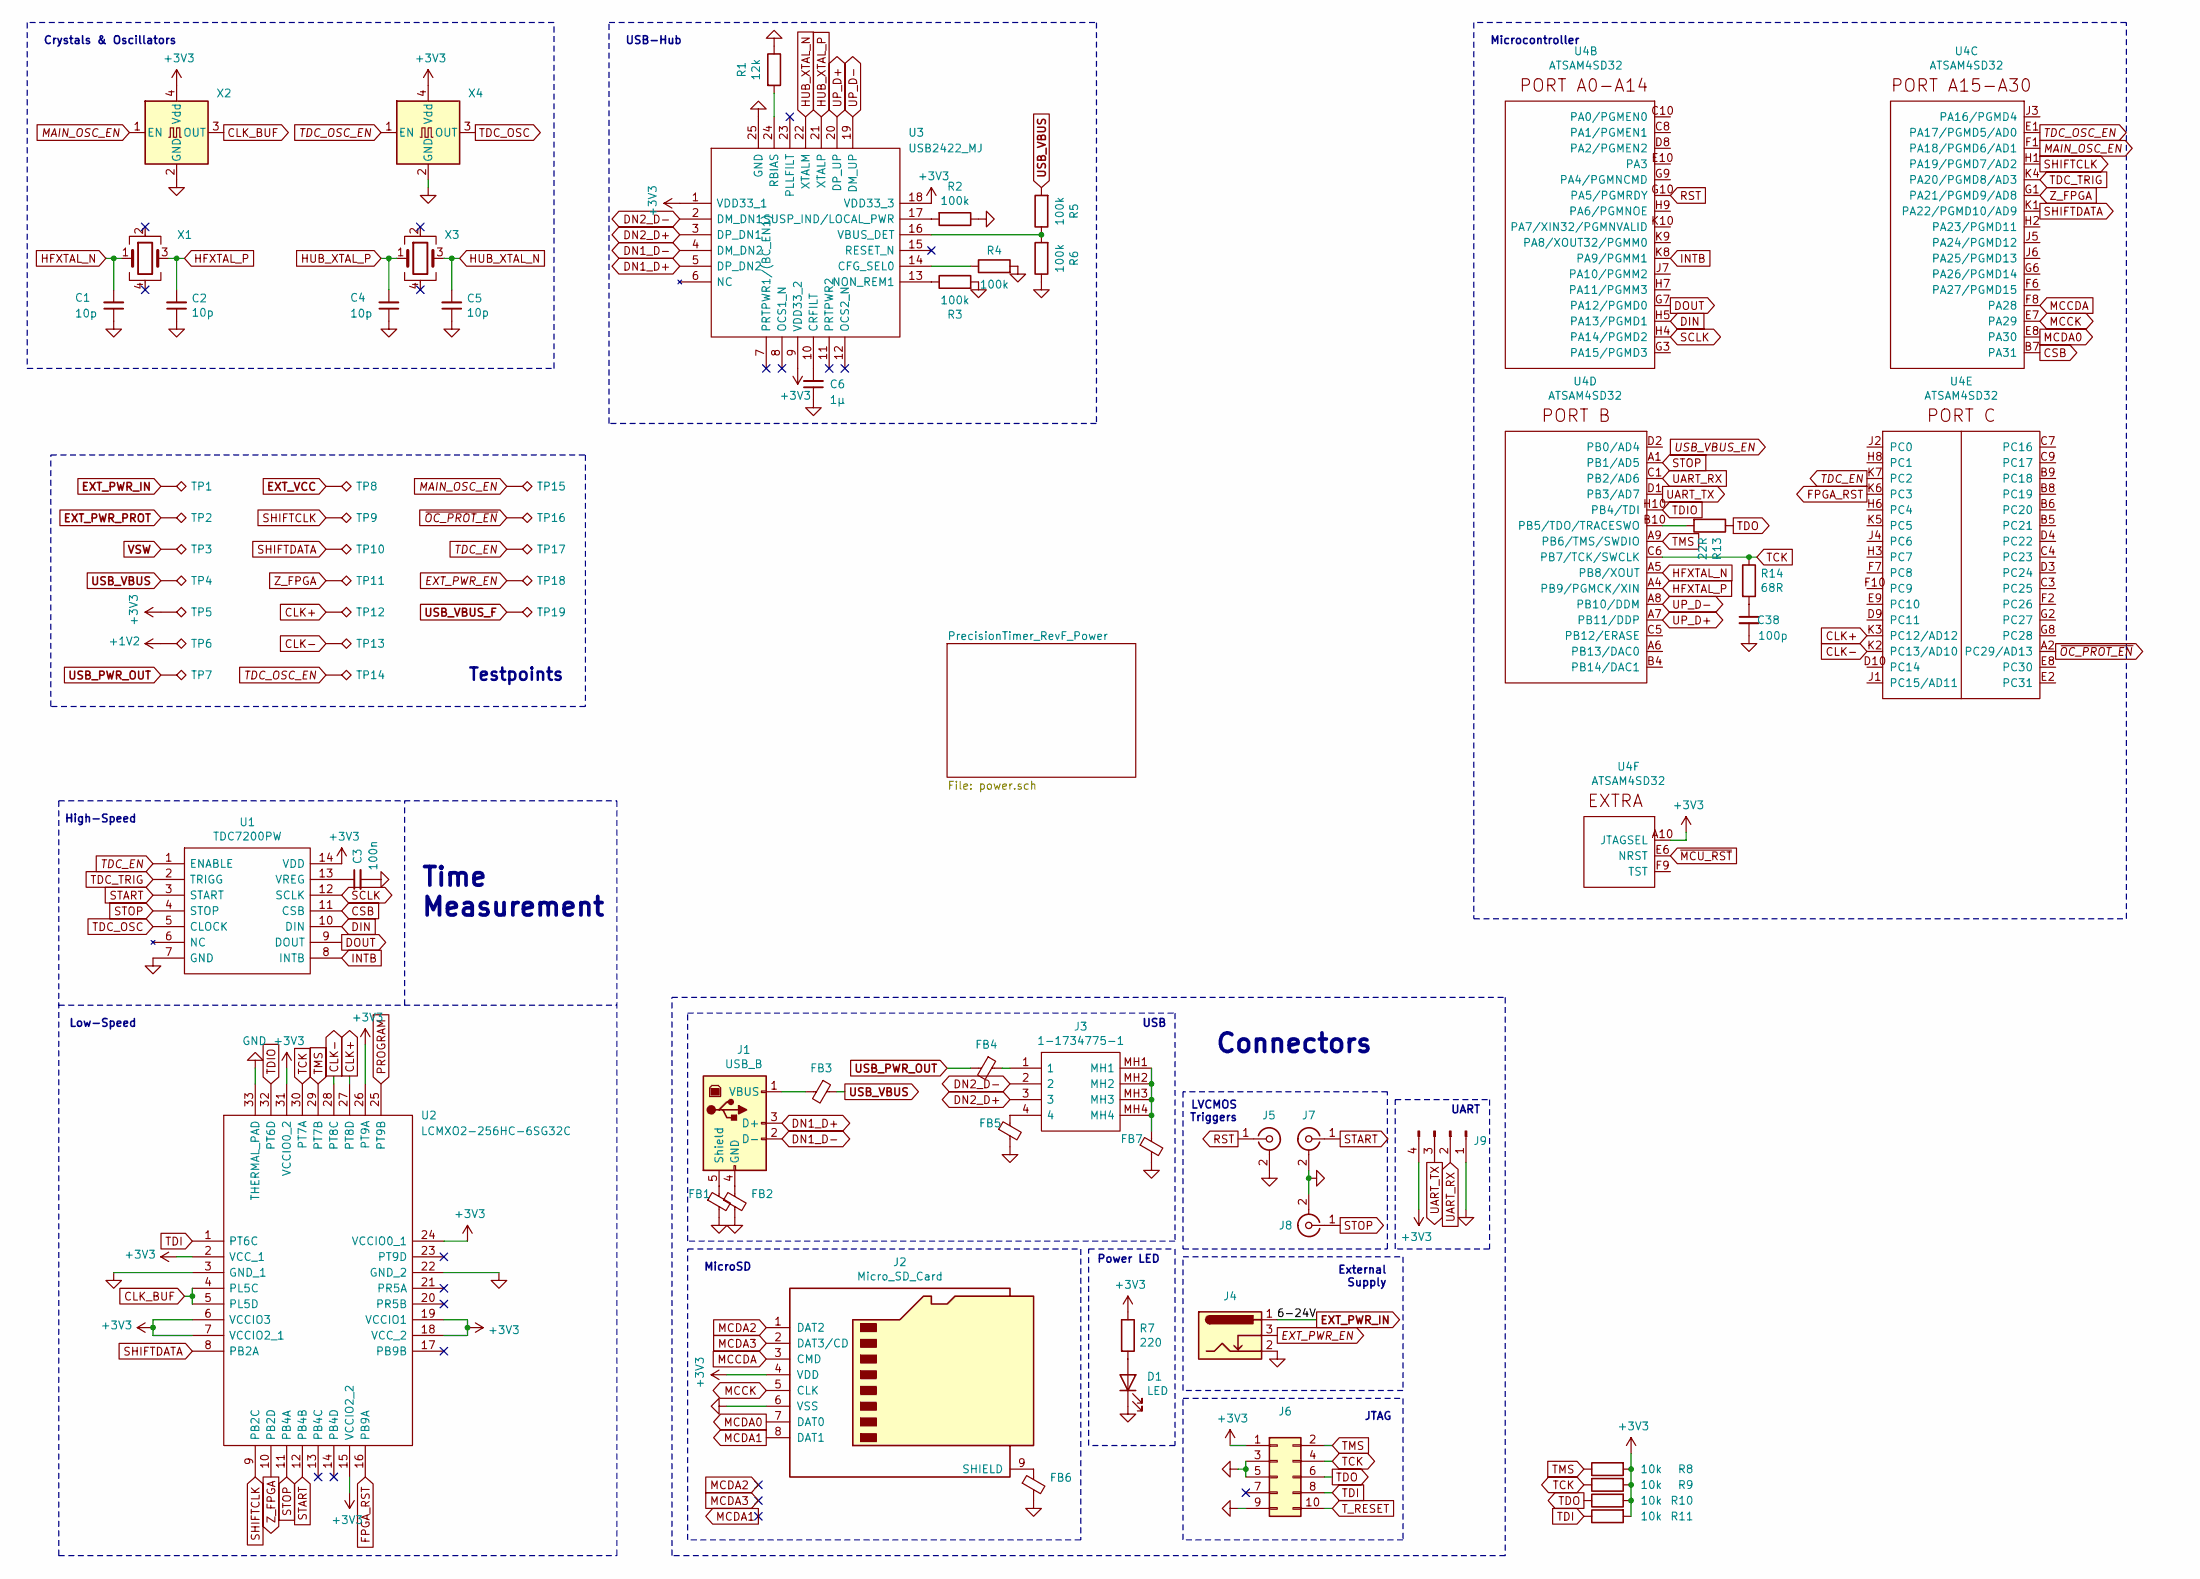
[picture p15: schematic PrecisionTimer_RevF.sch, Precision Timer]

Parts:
C1, C2, C4, C5: 10p; C_0402_1005Metric
C3: 100n; C_0603_1608Metric
C6: 1µ; C_0603_1608Metric
C38: 100p; C_0603_1608Metric
D1: LED; LED_D3.0mm
FB1, FB2, FB3, FB4, FB5, FB6, FB7: Ferrite_Bead_Small; L_0603_1608Metric
J1: USB_B; KUSBEXSMTBS1NBTR
J2: Micro_SD_Card; 475710001
J3: 1-1734775-1; 117347751; Mouser Part Number 571-1-1734775-1
J4: Barrel_Jack_Switch; BarrelJack_Wuerth_6941xx301002
J5, J7, J8: Conn_Coaxial; SMA_Molex_73251-2200_Horizontal
J6: Conn_02x05_Odd_Even; PinHeader_2x05_P1.27mm_Vertical_SMD
J9: Conn_01x04_Male; PinHeader_1x04_P2.54mm_Vertical_SMD_Pin1Left
R1: 12k; R_0402_1005Metric
R2, R3, R4, R5, R6: 100k; R_0402_1005Metric
R7: 220; R_0603_1608Metric
R8, R9, R10, R11: 10k; R_0603_1608Metric
R13: 22R; R_0603_1608Metric
R14: 68R; R_0603_1608Metric
TP1, TP2, TP3, TP4, TP5, TP6, TP7, TP8, TP9, TP10, TP11, TP12, TP13, TP14, TP15, TP16, TP17, TP18, TP19: TestPoint_Alt; TestPoint_Pad_D1.0mm
U1: TDC7200PW; SOP65P640X120-14N; Manufacturer_Part_Number TDC7200PW
U2: LCMXO2-256HC-6SG32C; QFN50P500X500X60-33N; Manufacturer_Part_Number LCMXO2-256HC-4SG32I
U3: USB2422_MJ; QFN50P400X400X100-25N-D; Mouser Part Number 579-USB2422/MJ
U4: ATSAM4SD32; TFBGA-100_9.0x9.0mm_Layout10x10_P0.8mm
X1: Crystal_16MHz; Crystal_SMD_2016-4Pin_2.0x1.6mm
X2: ASE-125MHz; Oscillator_SMD_SeikoEpson_SG210-4Pin_2.5x2.0mm
X3: Crystal_24MHz; Crystal_SMD_2016-4Pin_2.0x1.6mm
X4: ASE-016MHz; Oscillator_SMD_EuroQuartz_XO32-4Pin_3.2x2.5mm

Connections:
+1V2: TP6.1; also elsewhere on the board
+3V3: J2.4 (VDD), J6.1, J9.4, R7.1, R8.2, R9.2, R10.2, R11.2, TP5.1, U1.14 (VDD), U2.2 (VCC_1), U2.6 (VCCIO3), U2.7 (VCCIO2_1), U2.15 (VCCIO2_2), U2.18 (VCC_2), U2.19 (VCCIO1), U2.24 (VCCIO0_1), U2.26 (PT9A), U2.31 (VCCIO0_2), U3.1 (VDD33_1), U3.9 (VDD33_2), U3.18 (VDD33_3), U4.A10 (JTAGSEL), X2.4 (Vdd), X4.4 (Vdd); also elsewhere on the board
CLK+: TP12.1, U2.27 (PT8D), U4.K3 (PC12/AD12)
CLK-: TP13.1, U2.28 (PT8C), U4.K2 (PC13/AD10)
CLK_BUF: U2.4 (PL5C), U2.5 (PL5D), X2.3 (OUT)
CSB: U1.11 (CSB), U4.B7 (PA31)
DIN: U1.10 (DIN), U4.H5 (PA13/PGMD1)
DN1_D+: J1.3 (D+), U3.5 (DP_DN2)
DN1_D-: J1.2 (D-), U3.4 (DM_DN2)
DN2_D+: J3.3, U3.3 (DP_DN1)
DN2_D-: J3.2, U3.2 (DM_DN1)
DOUT: U1.9 (DOUT), U4.G7 (PA12/PGMD0)
EXT_PWR_EN: J4.3, TP18.1; also elsewhere on the board
EXT_PWR_IN: J4.1, TP1.1; also elsewhere on the board
EXT_PWR_PROT: TP2.1; also elsewhere on the board
EXT_VCC: TP8.1; also elsewhere on the board
FPGA_RST: U2.16 (PB9A), U4.K6 (PC3)
GND: C1.1, C2.1, C3.2, C4.1, C5.1, C6.1, C38.2, D1.1 (K), FB1.2, FB2.2, FB5.2, FB6.2, FB7.2, J2.6 (VSS), J4.2, J5.2 (Ext), J6.3, J6.5, J6.9, J7.2 (Ext), J8.2 (Ext), J9.1, R1.1, R2.1, R3.2, R4.2, R6.1, U1.7 (GND), U2.3 (GND_1), U2.22 (GND_2), U2.33 (THERMAL_PAD), U3.25 (GND), X2.2 (GND), X4.2 (GND); also elsewhere on the board
HFXTAL_N: C1.2, U4.A5 (PB8/XOUT), X1.1
HFXTAL_P: C2.2, U4.A4 (PB9/PGMCK/XIN), X1.3
HUB_XTAL_N: C5.2, U3.22 (XTALM), X3.3
HUB_XTAL_P: C4.2, U3.21 (XTALP), X3.1
INTB: U1.8 (INTB), U4.K8 (PA9/PGMM1)
MAIN_OSC_EN: TP15.1, U4.F1 (PA18/PGMD6/AD1), X2.1 (EN)
MCCDA: J2.3 (CMD), U4.F8 (PA28)
MCCK: J2.5 (CLK), U4.E7 (PA29)
MCDA0: J2.7 (DAT0), U4.E8 (PA30)
MCDA1: J2.8 (DAT1)
MCDA2: J2.1 (DAT2)
MCDA3: J2.2 (DAT3/CD)
unnamed: C3.1, U1.13 (VREG)
unnamed: C6.2, U3.10 (CRFILT)
unnamed: C38.1, R14.2
unnamed: D1.2 (A), R7.2
unnamed: FB1.1, J1.5 (Shield)
unnamed: FB2.1, J1.4 (GND)
unnamed: FB3.2, J1.1 (VBUS)
unnamed: FB4.1, J3.1
unnamed: FB5.1, J3.4
unnamed: FB6.1, J2.9 (SHIELD)
unnamed: FB7.1, J3.MH1, J3.MH2, J3.MH3, J3.MH4
unnamed: R1.2, U3.24 (RBIAS)
unnamed: R2.2, U3.17 (SUSP_IND/LOCAL_PWR)
unnamed: R3.1, U3.13 (NON_REM1)
unnamed: R4.1, U3.14 (CFG_SEL0)
unnamed: R5.1, R6.2, U3.16 (VBUS_DET)
unnamed: R13.2, U4.B10 (PB5/TDO/TRACESWO)
PROGRAM: U2.25 (PT9B)
RST: J5.1 (In), U4.G10 (PA5/PGMRDY)
SCLK: U1.12 (SCLK), U4.H4 (PA14/PGMD2)
SHIFTCLK: TP9.1, U2.9 (PB2C), U4.H1 (PA19/PGMD7/AD2)
SHIFTDATA: TP10.1, U2.8 (PB2A), U4.K1 (PA22/PGMD10/AD9)
START: J7.1 (In), U1.3 (START), U2.12 (PB4B)
STOP: J8.1 (In), U1.4 (STOP), U2.11 (PB4A), U4.A1 (PB1/AD5)
TCK: J6.4, R9.1, R14.1, U2.30 (PT7A), U4.C6 (PB7/TCK/SWCLK)
TDC_EN: TP17.1, U1.1 (ENABLE), U4.K7 (PC2)
TDC_OSC: U1.5 (CLOCK), X4.3 (OUT)
TDC_OSC_EN: TP14.1, U4.E1 (PA17/PGMD5/AD0), X4.1 (EN)
TDC_TRIG: U1.2 (TRIGG), U4.K4 (PA20/PGMD8/AD3)
TDI: J6.8, R11.1, U2.1 (PT6C)
TDIO: U2.32 (PT6D), U4.H10 (PB4/TDI)
TDO: J6.6, R10.1, R13.1
TMS: J6.2, R8.1, U2.29 (PT7B), U4.A9 (PB6/TMS/SWDIO)
T_RESET: J6.10
UART_RX: J9.2, U4.C1 (PB2/AD6)
UART_TX: J9.3, U4.D1 (PB3/AD7)
UP_D+: U3.20 (DP_UP), U4.A7 (PB11/DDP)
UP_D-: U3.19 (DM_UP), U4.A8 (PB10/DDM)
USB_PWR_OUT: FB4.2, TP7.1; also elsewhere on the board
USB_VBUS: FB3.1, R5.2, TP4.1; also elsewhere on the board
USB_VBUS_F: TP19.1; also elsewhere on the board
VSW: TP3.1; also elsewhere on the board
Z_FPGA: TP11.1, U2.10 (PB2D), U4.G1 (PA21/PGMD9/AD8)
~MCU_RST: U4.E6 (NRST)
~OC_PROT_EN: TP16.1, U4.A2 (PC29/AD13); also elsewhere on the board

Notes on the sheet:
Time Measurement
Connectors
Power LED
Microcontroller
LVCMOS Triggers
Low-Speed
USB
JTAG
External Supply
UART
Crystals & Oscillators
MicroSD
USB-Hub
High-Speed
Testpoints

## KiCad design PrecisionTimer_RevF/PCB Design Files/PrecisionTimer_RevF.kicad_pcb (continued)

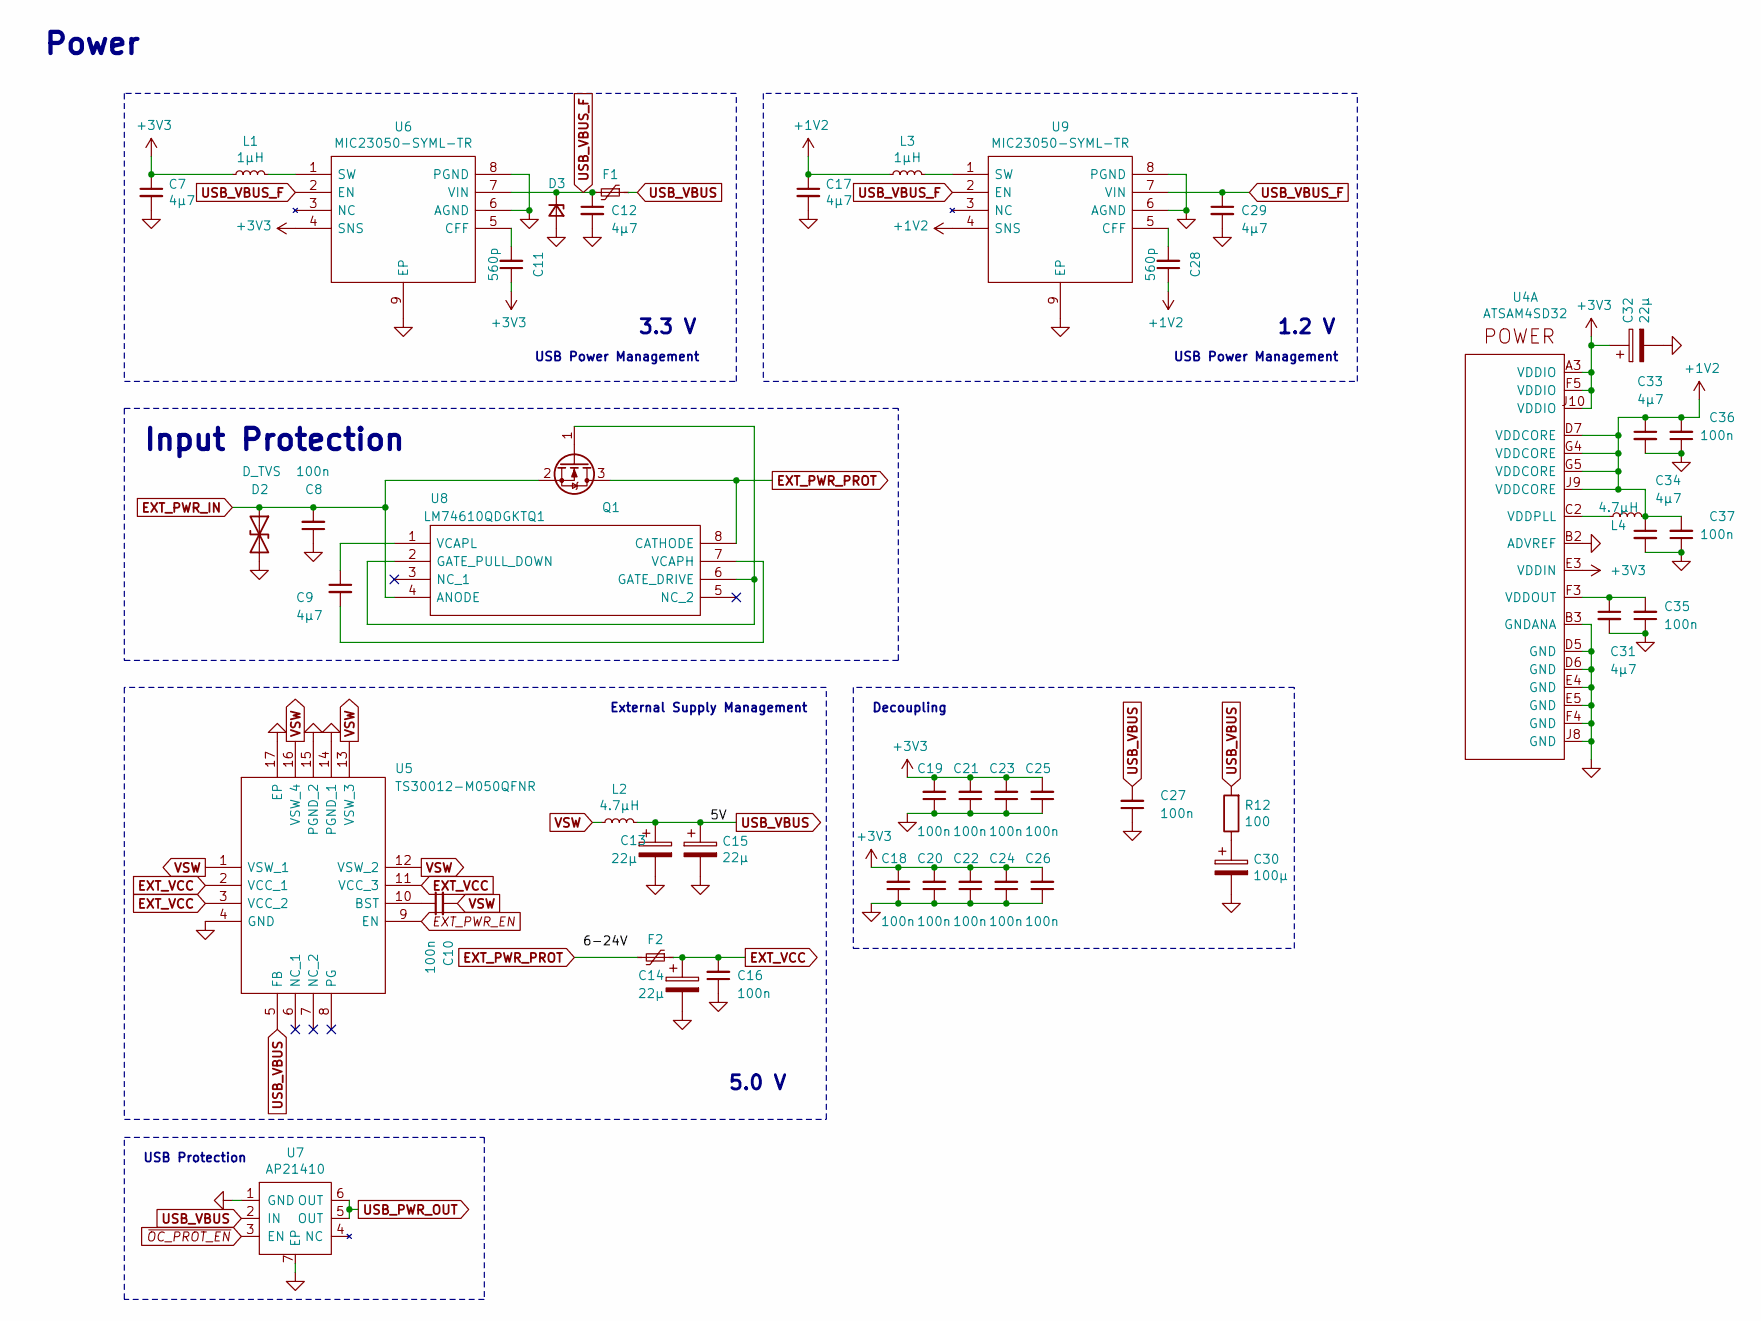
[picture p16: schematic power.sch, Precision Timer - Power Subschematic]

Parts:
C7, C9, C12, C17, C29, C31, C33, C34: 4µ7; C_0603_1608Metric
C8, C10, C16, C18, C19, C20, C21, C22, C23, C24, C25, C26, C27, C35, C36, C37: 100n; C_0603_1608Metric
C11, C28: 560p; C_0603_1608Metric
C13, C14, C15, C32: 22µ; C_0805_2012Metric
C30: 100µ; CP_Elec_5x5.4
D2: D_TVS; D_SMB
D3: D_Zener_Small; D_MiniMELF
F1, F2: Polyfuse_Small; Fuse_1206_3216Metric_Castellated
L1, L3: 1µH; L_0805_2012Metric
L2, L4: 4.7µH; L_0805_2012Metric
Q1: Q_NMOS_GSD; SOT-23
R12: 100; R_0805_2012Metric
U4: ATSAM4SD32; TFBGA-100_9.0x9.0mm_Layout10x10_P0.8mm
U5: TS30012-M050QFNR; QFN50P300X300X100-17N-D; Manufacturer_Part_Number TS30012-M050QFNR; Mouser Part Number 947-TS30012-M050QFNR
U6, U9: MIC23050-SYML-TR; SON50P200X200X90-9N; Manufacturer_Part_Number MIC23050-SYML-TR; Mouser Part Number 998-MIC23050-SYMLTR
U7: AP21410; DFN-6-1EP_2x1.8mm_P0.5mm_EP1.2x1.6mm
U8: LM74610QDGKTQ1; SOP65P490X110-8N; Manufacturer_Part_Number LM74610QDGKTQ1; Mouser Part Number 595-LM74610QDGKTQ1

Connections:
+1V2: C17.1, C28.1, C33.1, C34.1, C36.2, C37.2, L3.1, L4.2, U4.D7 (VDDCORE), U4.G4 (VDDCORE), U4.G5 (VDDCORE), U4.J9 (VDDCORE), U9.4 (SNS); also elsewhere on the board
+3V3: C7.1, C11.1, C18.2, C19.2, C20.2, C21.2, C22.2, C23.2, C24.2, C25.2, C26.2, C32.1, L1.1, U4.A3 (VDDIO), U4.E3 (VDDIN), U4.F5 (VDDIO), U4.J10 (VDDIO), U6.4 (SNS); also elsewhere on the board
EXT_PWR_EN: U5.9 (EN); also elsewhere on the board
EXT_PWR_IN: C8.2, D2.1 (A1), Q1.2 (S), U8.4 (ANODE); also elsewhere on the board
EXT_PWR_PROT: F2.2, Q1.3 (D), U8.8 (CATHODE); also elsewhere on the board
EXT_VCC: C14.1, C16.2, F2.1, U5.2 (VCC_1), U5.3 (VCC_2), U5.11 (VCC_3); also elsewhere on the board
GND: C7.2, C8.1, C12.2, C13.2, C14.2, C15.2, C16.1, C17.2, C18.1, C19.1, C20.1, C21.1, C22.1, C23.1, C24.1, C25.1, C26.1, C27.1, C29.2, C30.2, C31.2, C32.2, C33.2, C34.2, C35.1, C36.1, C37.1, D2.2 (A2), D3.2 (A), U4.B2 (ADVREF), U4.B3 (GNDANA), U4.D5 (GND), U4.D6 (GND), U4.E4 (GND), U4.E5 (GND), U4.F4 (GND), U4.J8 (GND), U5.4 (GND), U5.14 (PGND_1), U5.15 (PGND_2), U5.17 (EP), U6.6 (AGND), U6.8 (PGND), U6.9 (EP), U7.1 (GND), U7.7 (EP), U9.6 (AGND), U9.8 (PGND), U9.9 (EP); also elsewhere on the board
unnamed: C9.1, U8.1 (VCAPL)
unnamed: C9.2, U8.7 (VCAPH)
unnamed: C10.1, U5.10 (BST)
unnamed: C11.2, U6.5 (CFF)
unnamed: C28.2, U9.5 (CFF)
unnamed: C30.1, R12.1
unnamed: C31.1, C35.2, U4.F3 (VDDOUT)
unnamed: L1.2, U6.1 (SW)
unnamed: L3.2, U9.1 (SW)
unnamed: L4.1, U4.C2 (VDDPLL)
unnamed: Q1.1 (G), U8.2 (GATE_PULL_DOWN), U8.6 (GATE_DRIVE)
USB_PWR_OUT: U7.5 (OUT), U7.6 (OUT); also elsewhere on the board
USB_VBUS: C13.1, C15.1, C27.2, F1.1, L2.2, R12.2, U5.5 (FB), U7.2 (IN); also elsewhere on the board
USB_VBUS_F: C12.1, C29.1, D3.1 (K), F1.2, U6.2 (EN), U6.7 (VIN), U9.2 (EN), U9.7 (VIN); also elsewhere on the board
VSW: C10.2, L2.1, U5.1 (VSW_1), U5.12 (VSW_2), U5.13 (VSW_3), U5.16 (VSW_4); also elsewhere on the board
~OC_PROT_EN: U7.3 (EN); also elsewhere on the board

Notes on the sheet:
USB Power Management
Decoupling
External Supply Management
Power
USB Protection
3.3 V
1.2 V
5.0 V
Input Protection

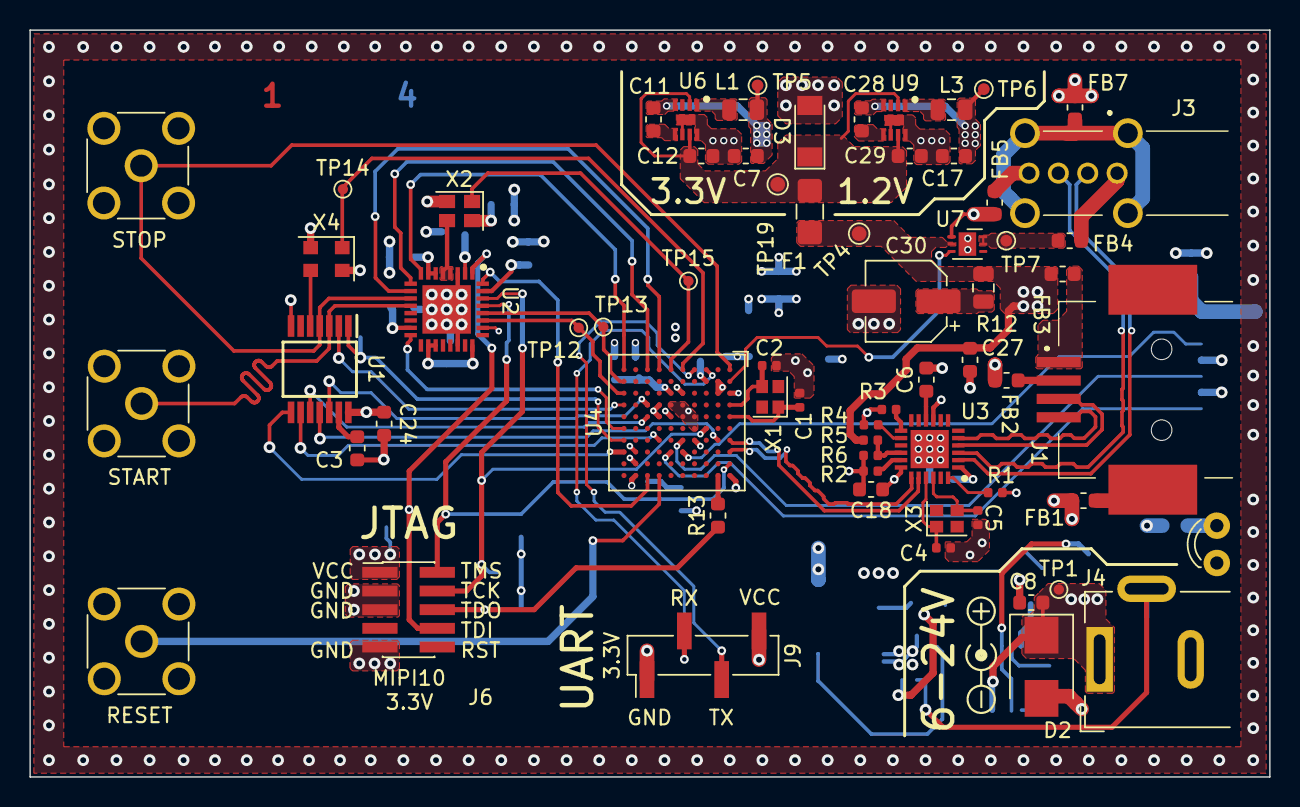
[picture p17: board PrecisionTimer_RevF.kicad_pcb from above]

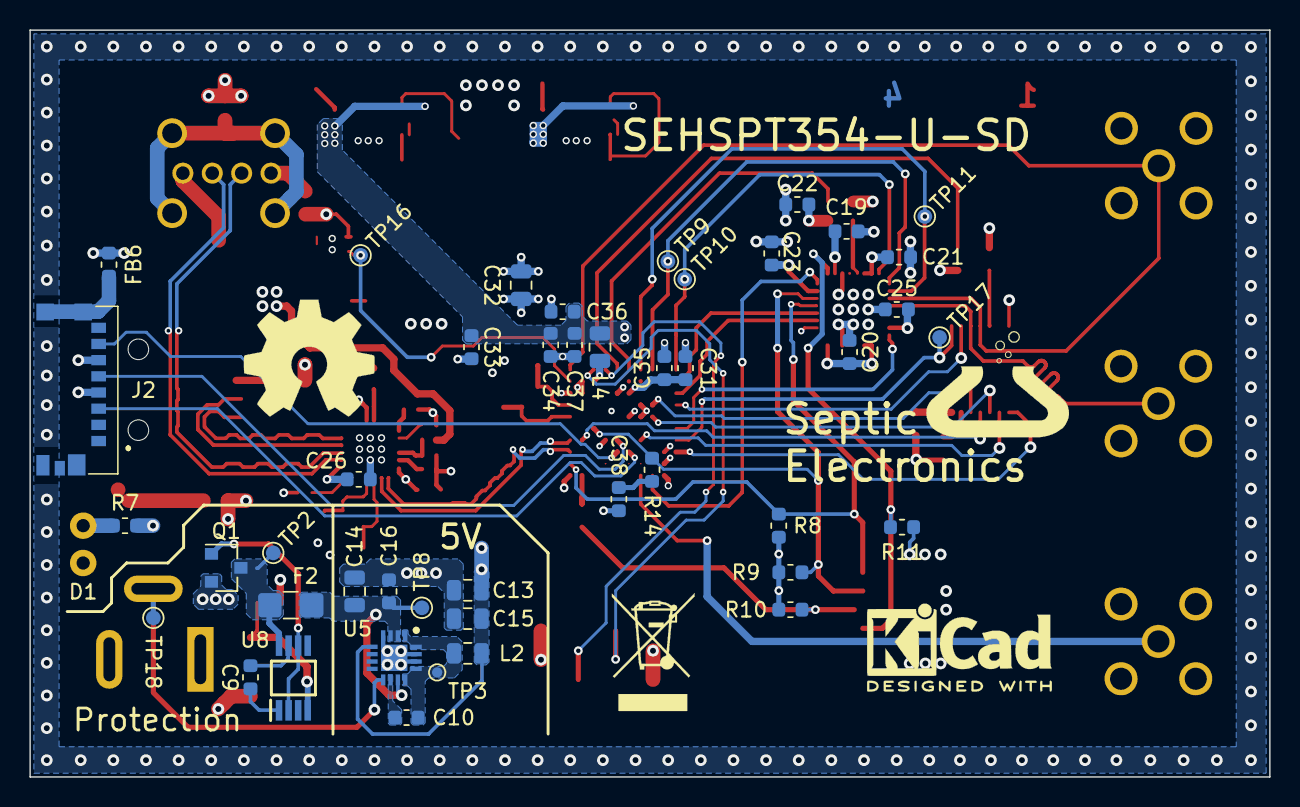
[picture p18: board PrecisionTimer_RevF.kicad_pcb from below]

Board: 4 copper layers, 84.3 x 50.8 mm, 110 parts (44 on the bottom side), 80 nets.

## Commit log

2020-07-25 Update and rename PrecisionTimer_RevF/PrecisionTimer_RevF.sch to PrecisionTimer_RevF/PCB Design Files/PrecisionTimer_RevF.sch
    [PrecisionTimer_RevF.sch]
2020-07-25 Rename PrecisionTimer_RevF/PrecisionTimer_RevF-cache.lib to PrecisionTimer_RevF/PCB Design Files/PrecisionTimer_RevF-cache.lib
2020-07-25 Rename PrecisionTimer_RevF/PrecisionTimer_RevF.kicad_pcb to PrecisionTimer_RevF/PCB Design Files/PrecisionTimer_RevF.kicad_pcb
    [PrecisionTimer_RevF.kicad_pcb]
2020-07-25 Rename PrecisionTimer_RevF/PrecisionTimer_RevF.kicad_pcb-bak to PrecisionTimer_RevF/PCB Design Files/PrecisionTimer_RevF.kicad_pcb-bak
2020-07-25 Rename PrecisionTimer_RevF/PrecisionTimer_RevF.net to PrecisionTimer_RevF/PCB Design Files/PrecisionTimer_RevF.net
2020-07-25 Rename PrecisionTimer_RevF/PrecisionTimer_RevF.pro to PrecisionTimer_RevF/PCB Design Files/PrecisionTimer_RevF.pro
2020-07-25 Rename PrecisionTimer_RevF/PrecisionTimer_RevF.sch-bak to PrecisionTimer_RevF/PCB Design Files/PrecisionTimer_RevF.sch-bak
2020-07-25 Rename PrecisionTimer_RevF/PrecisionTimer_RevF_back.kicad_pcb to PrecisionTimer_RevF/PCB Design Files/PrecisionTimer_RevF_back.kicad_pcb
    [PrecisionTimer_RevF_back.kicad_pcb]
2020-07-25 Rename PrecisionTimer_RevF/PrecisionTimer_RevF_back2.kicad_pcb to PrecisionTimer_RevF/PCB Design Files/PrecisionTimer_RevF_back2.kicad_pcb
    [PrecisionTimer_RevF_back2.kicad_pcb]
2020-07-25 Rename PrecisionTimer_RevF/power.sch to PrecisionTimer_RevF/PCB Design Files/power.sch
    [power.sch]
2020-07-25 Rename PrecisionTimer_RevF/power.sch-bak to PrecisionTimer_RevF/PCB Design Files/power.sch-bak
